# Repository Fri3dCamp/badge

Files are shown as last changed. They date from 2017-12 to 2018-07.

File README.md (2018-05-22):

# Fri3d Camp Badge 2018

De Badge voor Fri3d Camp 2018 is in volle ontwikkeling. Op dit ogenblik werken we aan het derde prototype, dat, als alles goed gaat nagenoeg de finale vorm zal hebben.

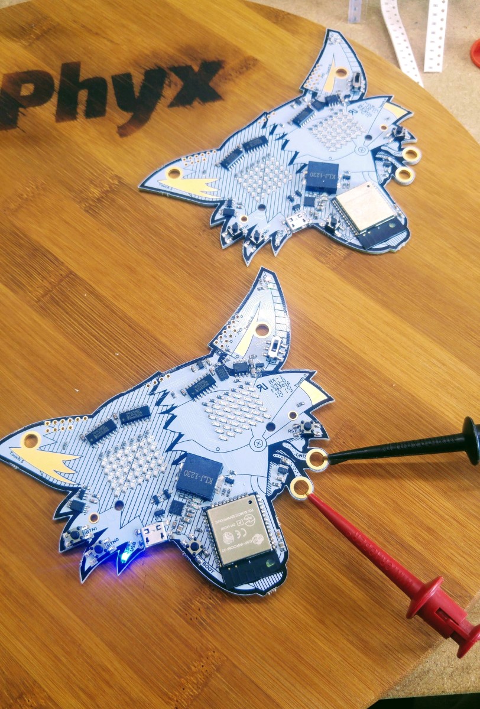
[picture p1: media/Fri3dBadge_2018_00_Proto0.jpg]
Fri3d Camp Badge prototype 3


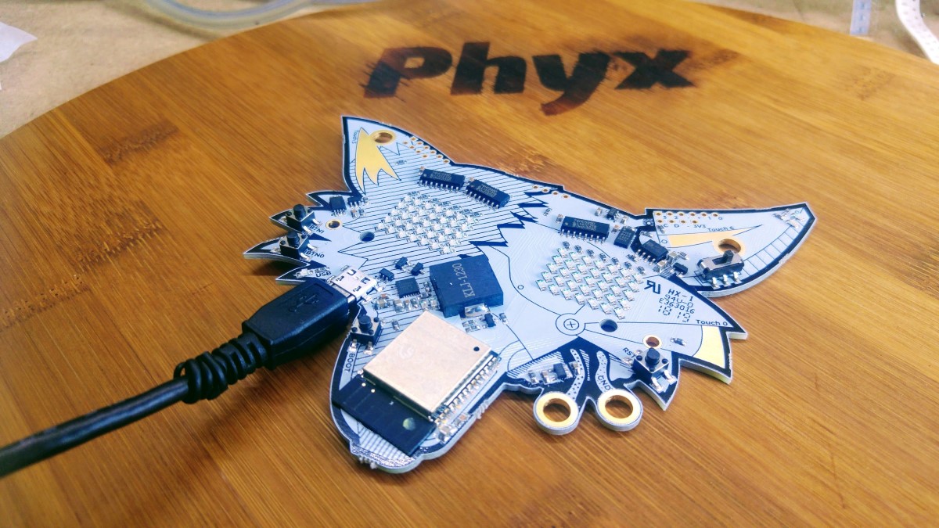
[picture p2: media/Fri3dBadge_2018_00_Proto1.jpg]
Fri3d Camp Badge prototype 3


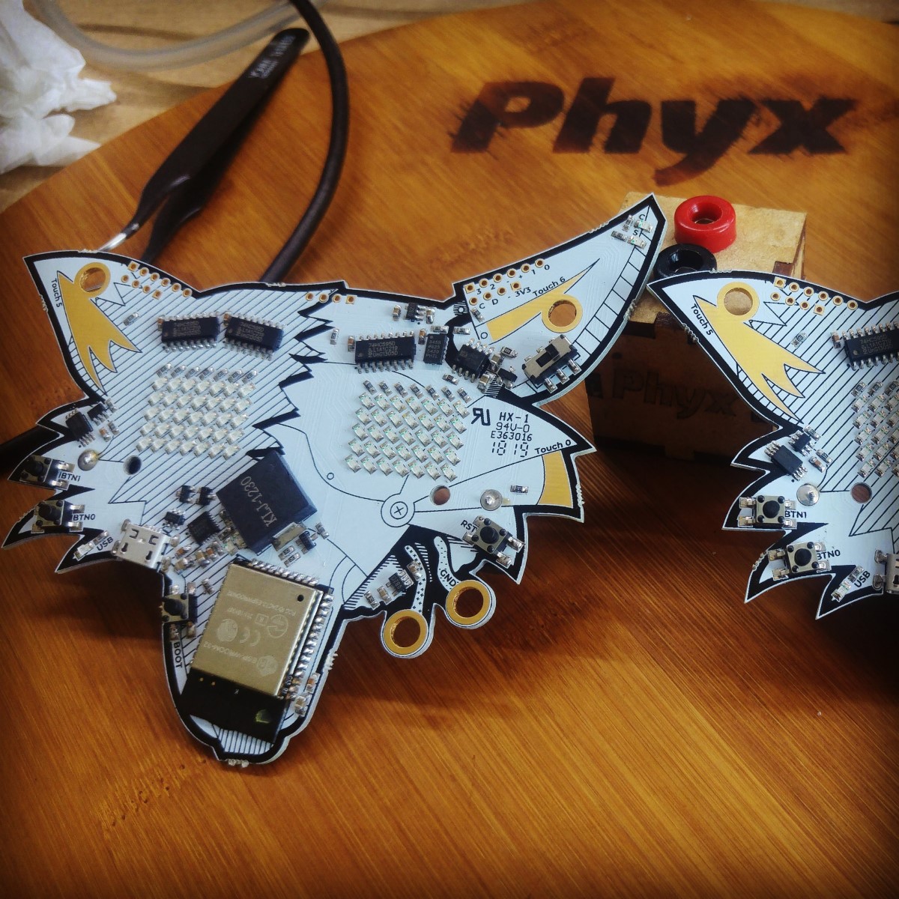
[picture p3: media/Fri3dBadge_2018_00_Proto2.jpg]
Fri3d Camp Badge prototype 3


More to come ...

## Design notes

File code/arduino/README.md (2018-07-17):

# Arduino code

The arduino code moved to its own repository: https://github.com/Fri3dCamp/Fri3dBadge

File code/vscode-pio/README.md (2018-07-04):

# Arduino library + Visual Studio Code + PlatformIO (PIO) tutorial

This tutorial shows how to program the Fri3d Camp badge using the Arduino
library in [Visual Studio Code](https://code.visualstudio.com/)
(VS Code for short), Microsoft's open source / freeware code editor in combination
with [PlatformIO](https://platformio.org/), an open source ecosystem for IoT
development.

This combination creates a powerful, fast, easy to use and cross platform IDE
for programming the Fri3d Camp badge.
PlatformIO will automatically download the necessary toolchain, compilers and
libraries and supports powerfull dependency management for Arduino libraries
(DHT, Servo, ...).
This way anyone can quickly set up a homogeneous, platform independent build
environment (Mac, Linux, Windows) and get started hacking the badge.

## Installation

* Download and install [Visual Studio Code](https://code.visualstudio.com/).
* Install the [PlatformIO IDE extension](https://platformio.org/get-started/ide?install=vscode)
in Visual Studio Code. You will be asked to reload VS Code a couple of times.
If everything went well you should be greated by the PIO Home screen in VS Code.
* You can read up on the PlatformIO documentation, browse through the supported
IoT platforms or check out some of the example projects.

## Configuration

PlatfromIO will generate a
[platformio.ini file](http://docs.platformio.org/en/latest/projectconf.html)
per project that you create.
In this file you can configure which IoT board your project uses (Arduino Uno,
ESP8266, ESP32, ...), which framework you use (Arduino, ESP-IDF, ...) and
optionally which libraries (and more importantly which version of those
libraries) your project uses (DHT temperature sensor, Servo library etc.).

This makes your project very portable between build environments.
Check out [the documentation at PlatfromIO](http://docs.platformio.org/en/latest/projectconf.html) for more information.

The Fri3d Camp badge uses the [espressif32 platform](http://docs.platformio.org/en/latest/platforms/espressif32.html).

## Example code

### Blink an LED

* Clone or download this Fri3d Camp repository if you haven't already done so.
* Open the blink example by opening the 'blink' folder under
/code/vscode-pio/examples in VS Code.
* Build the project by clicking the
checkmark in the PlatformIO toolbar at the bottom of the VS Code screen,
use the keyboard shortcut (Ctrl+Alt+b on Windows, Cmd+Shift+B on Mac) or
through the VS Code command palette (platformIO:Build).
PlatformIO should automatically download the ESP32 toolchain and its
dependencies and build the blink example without errors.
* Upload the program to your badge by clicking the right arrow icon in the
PlatformIO toolbar at the bottom, use the keyboard shortcut (Ctrl+Alt+u on
Windows, Option+Ctrl+u on Mac) or through the VS Code command palette
(platformIO:Upload).
If your badge is connected to your computer, PlatformIO should automatically
detect the port it's connected to and upload the program. The led on your
badge should start blinking.

### Use multiple cores

The ESP32 has 2 cores and is built with FreeRTOS, which allows multiple processes to run simultaneously on these cores. [This YouTube video](https://www.youtube.com/watch?v=k_D_Qu0cgu8) provides a great introduction on how to run multiple processes, use semaphores and communicate between processes with the ESP32.

The [dual core example](examples/dual_core) provides a simple example of multiple tasks running on different cores.

### Animate the eyes

TODO

### Connect to WiFi

TODO

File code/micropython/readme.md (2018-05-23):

# Fri3d Badge 2018 - MicroPython Edition

As it became a common phenomenon, every hacker camp should have their own badge. This year, we went the extra mile when designing the badge for the 2018 edition of Fri3dcamp, resulting in an awesome badge with enormous capabilities.

Apart from the very neat design (nicely done @toonvandeputte), the badge has been built around the ESP32, a very powerful microcontroller holding 2 cores as well as wifi and bluetooth (among a lot of other stuff). But there is more! We added 2 LED matrices, a piezo speaker an accelerometer and captive touch sensors to satisfy a lot of your maker needs.

If you need more, you can have a look at the Jewels; plug-on extensions providing even more functionality to the badge. Or maybe you want to design your own Jewel?     
 
We are working hard to make the badge something that stands out, so make sure to get back once in a while to check on our progress. For now, most information can be found in the docs folder.
 
## The Badge

Fri3d Camp Badge prototype 3

The badge contains the following hardware capabilities:

| component | status | description |
|---|---|---|
| Wifi | working | Connect to a wifi accesspoint or router. |
| Matrix | working | Two 5x7 LED matrices, representing eyes. |
| Accelero | working | Accelerometer measuring acceleration. |
| Buzzer | working | A piezo speaker to make some noise. |
| Touch | partially | Captive touch sensors. |
| Buttons | issues | Regular push buttons. |

## Jewels
Jewels are plug-on extensions providing extra functionality to the badge. 

### Servo Jewel
The Servo Jewel provides the badge with the ability to control up to 4 servo's. It is uses in the Robot Kit to move the legs around, but can be used in any situation where up to 4 servos have to be controlled.

## Kits
Kits are units which transforms the badge into something totally new.

### Robot Kit
The robot kit transforms the badge into a bipedal robot capable of moving around.
 
## Issues
### Buttons
Buttons do not seem to react to input. The pin values do not change during presses or releases.

### Touch Sensors
touch sensor 0 does not seem to be responding.

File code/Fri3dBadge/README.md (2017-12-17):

# Fri3d Badge Arduino Library

Deze hele folder moet je in je Arduino Libraries folder plaatsen.

Als je de hele Fri3d Badge GitHub repository hebt, kan je dit op een Unix systeem (bvb MacOS) ook doen door een link te leggen vertrekkende van de folder waar de `Fri3dBadge` folder zich bevindt.

```bash
$ ln -s `pwd`/Fri3dBadge ~/Documents/Arduino/libraries/
```

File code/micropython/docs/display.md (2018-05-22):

# Fri3dBadge Display Module

## Matrix
Er zijn twee LED matrices beschikbaar op de badge. Elke LED matrix heeft 5 rijen en 7 kolommen en je kan elke led afzonderlijk aan zetten.

### Hardware
Elk van de twee matrices is opgebouwd uit 35 blauwe LED's volgens een matrix structuur waarbij de kolommen de negatieve pool en de rijen de positieve pool voorstellen. Dit wil dus zeggen dat wanneer je aan 1 kolom een ground (GND, -) aansluit en aan 1 rij een vcc (3.3V, +) dat de led op het kruispunt van de rij en de kolom zal oplichten.
Natuurlijk is het vrij moeilijk om 35 led's aan te sturen met 1 microcontroller, aangezien we daarvoor niet voldoende pinnen vrij hebben op de microcontroller. Om dat op te lossen maken we gebruik van shift registers. Hierdoor hebben we maar 4 pinnen nodig om in totaal 70 led's aan te sturen.

Meer informatie over shift registers kan je vinden op [http://artimesdiy.nl/index.php?Itemid=76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](artimesdiy.nl)

### Software
Wanneer je binnen micropython de matrices wil gebruiken, dan kan je dit doen door middel van de ```Matrices``` klasse binnen de display module.

```python
from display import Matrices

matrices = Matrices()
```

Eenmaal je de matrices instantie beschikbaar hebt, kan je led's aan zetten door middel van de ```set(matrix, x, y)``` functie:

```python
# zet van de eerste matrix de led in de linker benedenhoek aan
matrices.set(0, 0, 0)
```

Je kan de display terug leeg maken door de ```clear()``` functie te gebruiken:

```python
matrices.clear()
```

Er draait een apparte thread op de 2e CPU die er voor zorgt dat de LED's uiteindelijk gezet worden

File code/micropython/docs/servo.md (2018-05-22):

# Servo Module

## Servo
Je kan hobby servo's aansturen met de badge. Hiervoor heb je wel een extra power board nodig omdat de servo's zelf enorm veel stroom verwachten.

### Hardware
Een hobby servo werkt op basis van een PWM (Pulse Width Modulation) signaal. Dit komt er eigenlijk op neer dat de tijd dat het signaal hoog is gebruikt wordt om gegevens door te geven. Het is dus cruciaal voor de software om binnen de juiste tijdsgrenzen te blijven. Hobby servo's verschillen ook nogal wanneer het op deze tijdsgrenzen aankomt, dus het kan zijn dat je je code straks gaat moeten aanpassen op jouw specifieke servo's.

### Software

TBD

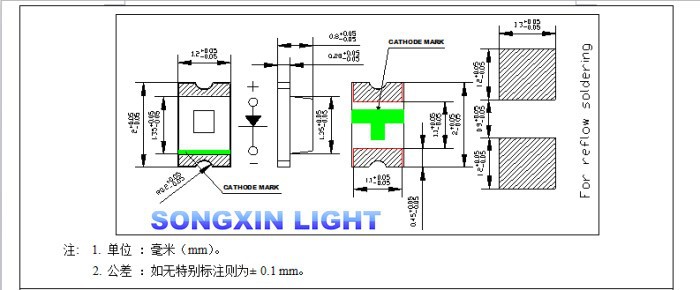
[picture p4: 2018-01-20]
datasheets/yellow-led.jpg

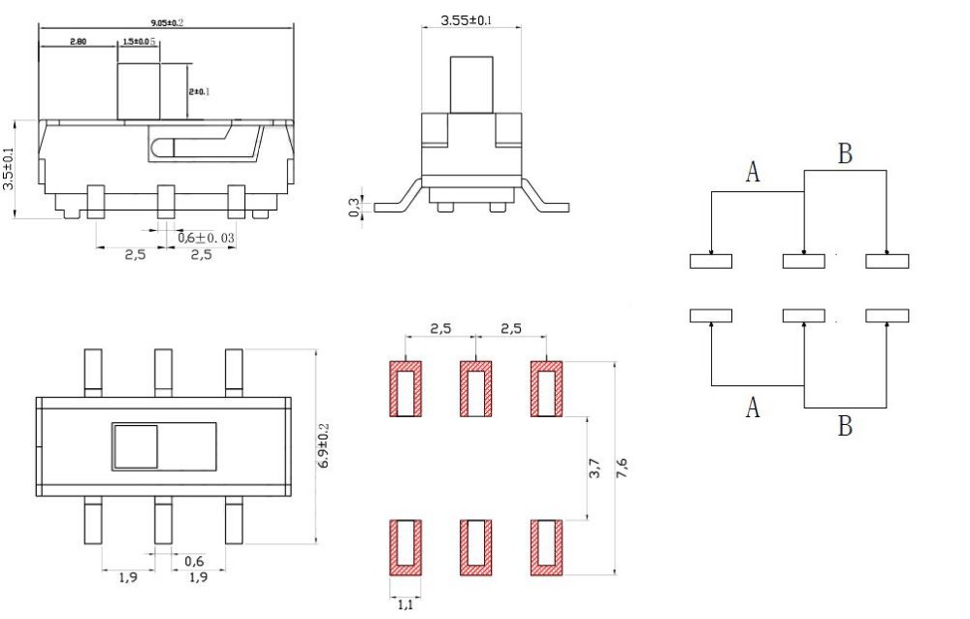
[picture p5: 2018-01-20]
datasheets/slide-switch.jpg

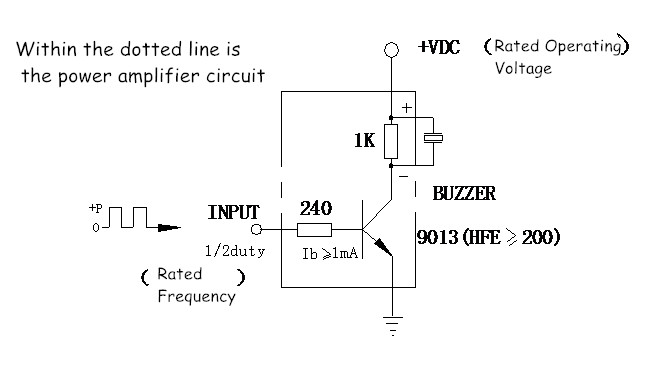
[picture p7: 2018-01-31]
datasheets/klj-1230.jpg

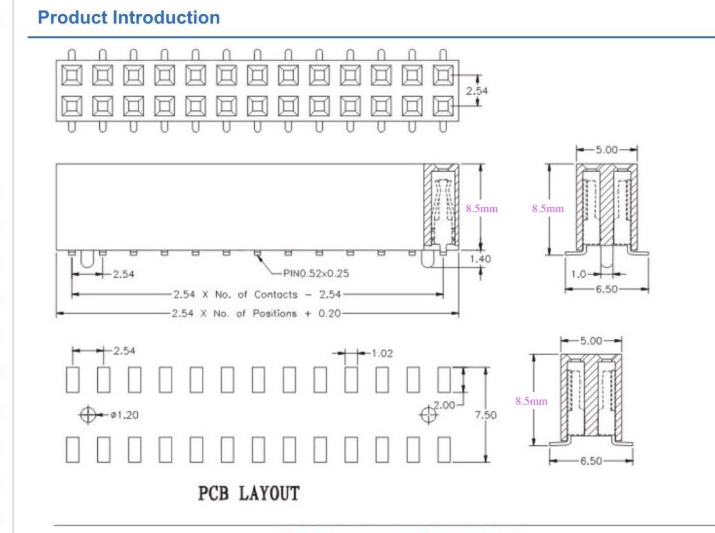
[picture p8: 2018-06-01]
datasheets/2x6_header_SMD.jpg

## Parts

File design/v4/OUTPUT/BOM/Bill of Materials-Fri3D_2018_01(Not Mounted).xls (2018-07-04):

Bill of Materials |  |  | Fri3D Badge 2018
Project: |  | Fri3D_2018_01.PrjPcb
Revision: |  | 01
Variant: |  | Not Mounted
Creation Date: | 13/06/2018 | 17:10:01
Print Date: | 2018-06-13 | 17:38:40
Footprint | Comment | LibRef | Designator | Value | Description | Supplier 1 | Supplier PN 1 | Qty
MPD_BH-18650-PC | 18650 Battery holder | 18650 Battery holder BH-18650-PC | BAT1 | BH-18650-PC |  | Digikey |  | 1
CUI_CMT-1203-SMT | 12x12x3mm Piezo Buzzer Transducer 81dB | BUZ # CUI CMT-1203-SMT | BUZ1 | CMT-1203-SMT | Crystal Oscillator | Digikey | 102-2197-1-ND | 1
C0603_N |  | CAP # 100nF 16V 0603 | C1, C3, C5, C6, C7, C12, C17, C19 | 100nF 16V | Capacitor Ceramic |  |  | 8
C0805_N | CAP_CERAMIC | CAP # 10uF 10V 0805 | C4, C15, C16, C18, C20 | 10uF 10V | Capacitor Ceramic | Farnell | 2320859 | 5
C0603_N | CAP_CERAMIC | CAP # 1uF 16V 0603 | C8, C9, C10, C11 | 1uF 16V | Capacitor Ceramic | Farnell | 2320814 | 4
NXP_SOT457 | TVS Diode Dual USB | TVS # IP4220CZ6 Dual USB | D1 | IP4220CZ6 |  | Farnell | 2143248 | 1
LED_0805_BL | Default 0805 Blue LED | LED # Blue 0805 | D2, D3, D4, D5, D6, D7, D8, D9, D10, D11, D12, D13, D14, D15, D16, D17, D18, D19, D20, D21, D22, D23, D24, D25, D26, D27, D28, D29, D30, D31, D32, D33, D34, D35, D36, D37, D38, D39, D40, D41, D42, D43, D44, D45, D46, D47, D48, D49, D50, D51, D52, D53, D54, D55, D56, D57, D58, D59, D60, D61, D62, D63, D64, D65, D66, D67, D68, D69, D70, D71, D76 |  |  | Farnell | 2217980 | 71
LED_0805_GR | Default 0805 Green LED | LED # Green 0805 | D72, D75 |  |  | Farnell | 2099239 | 2
LED_0805_RD | Default 0805 Red LED | LED # Red 0805 | D73, D74 |  |  | Farnell | 2099236 | 2
FCI_10118194-0001LF | Amphenol FCI 10118194-0001LF Micro USB 1.8A TH Lock | USB # Micro B TH Amphenol 10118194-0001LF | J2 | 10118194-0001LF |  | Farnell | 2668482 | 1
ESP-WROOM-32 | ESP-32 based ESP-WROOM-32 | WiFi # MOD ESP-WROOM-32 | MOD1 | ESP-WROOM-32 | WiFi # MOD ESP-WROOM-32 | Espressif | ESP-WROOM-32 | 1
WE_610312243021_POST | Receptacle 6x2 SMD low profile | Receptacle # 2.54mm dual row 12way 610312243021 | P1, P2 | 610312243021 |  | Wurth | 610312243021 | 2
R0603_N | RESISTOR | RES # 1K2 0603 | R1, R2, R18, R21, R22, R23, R24, R25, R26, R27 | 1K2 |  |  |  | 10
R0603_N | RESISTOR | RES # 100R 0603 | R3, R4, R5, R6, R7, R8, R9, R10, R11, R12, R13, R14, R15, R16, R17, R20, R30, R37, R38 | 100R |  |  |  | 19
R0603_N | RESISTOR | RES # 10K 0603 | R28, R29, R31, R34, R35, R36, R39, R40 | 10K |  | Farnell | 2502397 | 8
WE_430181038816 | 4.5x4.5mm tact SMD H3,8mm | SW # TACT small 4.5x4.5mm SMD WS-TASV | SW1, SW2, SW3, SW4 | 430181038816 |  | Wurth | 430181038816 | 4
MSS22D18 | Mini slide switch 2P2T | SW # 2P2T mini slide MSS22D18 | SW5 | MSS22D18 |  | AliExpress | MSS22D18 | 1
TSSOP_8_65P | Dual N-Ch MOSFET Common Drain | FS8205A Dual N-Ch common Drain for DW01-P | T1 | FS8205A |  | AliExpress | FS8205A | 1
SOT23-3 | 0.2A N-Ch MOSFET Vgs 3.2 | BSS138 N-Ch MOSFET 0.2A 3.2Vgs 60Vds | T2, T3, T4 | BSS138 |  | Farnell | 2432717 | 3
AD_CC-14-1 | 3-Axis, ±2 g/±4 g/±8 g/±16 g Digital Accelerometer | ACCELERO # ADXL345 | U1 | ADXL345BCCZ |  | Farnell | 1853935 | 1
SOIC_N_16 | 8-Bit Shift Registers With 3-State Output Registers | IOEXP # SHIFT 74HC595 8-bit | U2, U3, U4 | 74HC595 |  | Farnell | 1278491 | 3
SOT23-5 | 3V3 LDO 700mA 50mV | LDO # 3V3 XC6210B33 | U5, U6 | XC6210B332MR |  | Farnell | 1057803 | 2
SOT23-6 | DW01-P single cell lithium protection | PWR # DW01-P Lithium protection | U7 | DW01-P |  | Aliexpress | DW01-P | 1
SOIC_N_8_TH | Single Cell LiIon charger max 1A | CHG # TP4056 LiIon 1A | U8 | TP4056 |  | Aliexpress | TP4056 | 1
QFN_24 | USB to UART 3.3-5V | CP2102N # QFN24 USB UART | U9 | CP2102N-A01-GQFN24 |  | Farnell | 2577278 | 1
 |  |  |  |  |  |  |  | 154
Approved |  | Notes

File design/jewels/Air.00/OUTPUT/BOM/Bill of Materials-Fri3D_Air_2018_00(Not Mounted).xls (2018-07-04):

Bill of Materials |  |  | Fri3D Air 2018
Project: |  | Fri3D_Air_2018_00.PrjPcb
Revision: |  | 00
Variant: |  | Not Mounted
Creation Date: | 21/05/2018 | 22:15:40
Print Date: | 2018-05-23 | 15:10:44
Footprint | Comment | LibRef | Designator | Value | Description | Supplier 1 | Supplier Part Number 1 | Quantity | Quantity
C0805_N | CAP_CERAMIC | CAP # 10uF 10V 0805 | C2, C6 | 10uF 10V | Capacitor Ceramic | Farnell | 2320859 | 2
C0603_N |  | CAP # 100nF 16V 0603 | C4 | 100nF 16V | Capacitor Ceramic |  |  | 1
ON_SOD-123FL | NTS260SFT1G Schottky Rectifier, Single, 60 V, 2 A, SOD-123, 650 mV | Schottky # NTS260SFT1G | D1 | NTS260SFT1G |  | Farnell | 2473419 | 1 | Farnell | 2473419
SNL_SWPA4020 | SWPA4020S4R7MT | IND # 4u7H SWPA4020 | L1 | 4u7H |  | China | SWPA4020S4R7MT | 1 | Farnell | 2771305
WE_68800511722 | Header 2.5mm RA Shrouded 5 | HDR # RA SHR 2.5mm 5way - 68800511722 | P1 | 68800511722 |  | Wurth | 68800511722 | 1
HDR1X6 | Header 6 | Pin Header 2.54mm 6way | P2 |  |  |  |  | 1
HDR1X5 | Header 5 | Pin Header 2.54mm 5way | P3 |  |  |  |  | 1
HDR1X4 | Header 4 | Pin Header 2.54mm 4way | P5, P6 |  |  |  |  | 2
R0603_N | RESISTOR | RES # 82K 0603 | R1 | 82K |  |  |  | 1
R0603_N | RESISTOR | RES # 10K 0603 | R2 | 10K |  | Farnell | 2502397 | 1
R0603_N | RESISTOR | RES # 1K 0603 | R3 | 1K |  |  |  | 1
SOT23-6 | High Efficiency 1.2MHz 2A Step Up Converter SX1308 | PWR # Boost SX1308 | U1 | SX1308 |  |  |  | 1
 |  |  |  |  |  |  |  | 14
Approved |  | Notes

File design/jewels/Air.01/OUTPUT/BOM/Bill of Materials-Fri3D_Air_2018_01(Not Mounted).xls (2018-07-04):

Bill of Materials |  |  | Fri3D Air 2018
Project: |  | Fri3D_Air_2018_01.PrjPcb
Revision: |  | 01
Variant: |  | Not Mounted
Creation Date: | 12/06/2018 | 21:47:38
Print Date: | 2018-06-14 | 8:22:58
Footprint | Comment | LibRef | Designator | Value | Description | Supplier 1 | Supplier Part Number 1 | Qty
C0805_N | CAP_CERAMIC | CAP # 10uF 10V 0805 | C2, C6 | 10uF 10V | Capacitor Ceramic | Farnell | 2320859 | 2
C0603_N |  | CAP # 100nF 16V 0603 | C4 | 100nF 16V | Capacitor Ceramic |  |  | 1
TS_SOD128 | TSS83L45 MWG Schottky ULTRAFAST, 3A, 45V | Schottky # TSS83L45MWG 3A 45V | D1 | TSS83L45 MWG |  | Digi-key | TSS83L45MWGCT-ND | 1
SNL_SWPA4020 | SWPA4020S4R7MT | IND # 4u7H SWPA4020 | L1 | 4u7H |  | China | SWPA4020S4R7MT | 1
WE_68800511722 | Header 2.5mm RA Shrouded 5 | HDR # RA SHR 2.5mm 5way - 68800511722 | P1 | 68800511722 |  | Wurth | 68800511722 | 1
HDR1X6 | Header 6 | Pin Header 2.54mm 6way | P2 |  |  |  |  | 1
HDR1X5 | Header 5 | Pin Header 2.54mm 5way | P3 |  |  |  |  | 1
HDR1X4 | Header 4 | Pin Header 2.54mm 4way | P5, P6 |  |  |  |  | 2
R0603_N | RESISTOR | RES # 82K 0603 | R1 | 82K |  |  |  | 1
R0603_N | RESISTOR | RES # 10K 0603 | R2 | 10K |  | Farnell | 2502397 | 1
R0603_N | RESISTOR | RES # 1K 0603 | R3 | 1K |  |  |  | 1
SOT23-6 | High Efficiency 1.2MHz 2A Step Up Converter SX1308 | PWR # Boost SX1308 | U1 | SX1308 |  |  |  | 1
 |  |  |  |  |  |  |  | 14
Approved |  | Notes

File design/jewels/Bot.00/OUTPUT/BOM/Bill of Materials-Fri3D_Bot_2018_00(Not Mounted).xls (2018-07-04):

Bill of Materials |  |  | Fri3D Bot 2018
Project: |  | Fri3D_Bot_2018_00.PrjPcb
Revision: |  | 00
Variant: |  | Not Mounted
Creation Date: | 12/06/2018 | 22:04:56
Print Date: | 2018-06-14 | 8:24:33
Footprint | Comment | LibRef | Designator | Value | Description | Supplier 1 | Supplier Part Number 1 | Qty
MPD_BH-18650-PC | 18650 Battery holder | 18650 Battery holder BH-18650-PC | BAT1 | BH-18650-PC |  | Digikey |  | 1
C1210_N | CAP_CERAMIC | CAP # 22uF 10V 1210 X5R | C3, C7, C9, C13 | 22uF 10V | Capacitor Ceramic |  |  | 4
C0805_N | CAP_CERAMIC | CAP # 10uF 10V 0805 | C4, C5, C6, C8, C10, C11 | 10uF 10V | Capacitor Ceramic | Farnell | 2320859 | 6
C0603_N |  | CAP # 100nF 16V 0603 | C12 | 100nF 16V | Capacitor Ceramic |  |  | 1
TS_SOD128 | TSS83L45 MWG Schottky ULTRAFAST, 3A, 45V | Schottky # TSS83L45MWG 3A 45V | D1, D2 | TSS83L45 MWG |  | Digi-key | TSS83L45MWGCT-ND | 2
LED_0805_RD | Default 0805 Red LED | LED # Red 0805 | D3, D5 | Red |  | Farnell | 2099236 | 2
LED_0805_GR | Default 0805 Green LED | LED # Green 0805 | D4 | Green |  | Farnell | 2099239 | 1
FCI_10118194-0001LF | Amphenol FCI 10118194-0001LF Micro USB 1.8A TH Lock | USB # Micro B TH Amphenol 10118194-0001LF | J1 | 10118194-0001LF |  | Farnell | 2668482 | 1
SNL_SWPA4020 | SWPA4020S4R7MT | IND # 4u7H SWPA4020 | L5, L6 | 4u7H |  | China | SWPA4020S4R7MT | 2
HDR1X6 | Header 6 | Pin Header 2.54mm 6way | P1 |  |  |  |  | 1
HDR1X4 | Header 4 | Pin Header 2.54mm 4way | P3 |  |  |  |  | 1
HDR1X3 | Header 3 | Pin Header 2.54mm 3way | P4, P6, P7, P8 |  |  |  |  | 4
R0603_N | RESISTOR | RES # 82K 0603 | R1, R4 | 82K |  |  |  | 2
R0603_N | RESISTOR | RES # 10K 0603 | R2, R5 | 10K |  | Farnell | 2502397 | 2
R0603_N | RESISTOR | RES # 1K2 0603 | R3, R6, R7, R8, R9, R10, R11, R18 | 1K2 |  |  |  | 8
R0603_N | RESISTOR | RES # 100R 0603 | R17 | 100R |  |  |  | 1
SK-12D07 | mini Switch 1 pole double throw right angle | SW 1P2T micro RA SK-12D07 | SW1 | SK-12D07 |  | AliExpress | SK-12D07 | 1
TSSOP_8_65P | Dual N-Ch MOSFET Common Drain | FS8205A Dual N-Ch common Drain for DW01-P | T1 | FS8205A |  | AliExpress | FS8205A | 1
SOT23-6 | High Efficiency 1.2MHz 2A Step Up Converter SX1308 | PWR # Boost SX1308 | U1, U2 | SX1308 |  |  |  | 2
SOIC_N_8_TH | Single Cell LiIon charger max 1A | CHG # TP4056 LiIon 1A | U3 | TP4056 |  | Aliexpress | TP4056 | 1
SOT23-6 | DW01-P single cell lithium protection | PWR # DW01-P Lithium protection | U7 | DW01-P |  | Aliexpress | DW01-P | 1
 |  |  |  |  |  |  |  | 45
Approved |  | Notes

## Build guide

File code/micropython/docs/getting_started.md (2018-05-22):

# Getting Started

## Connect the badge to your laptop or pc
You can connect the badge to your laptop or pc using a micro-usb cable. In some cases you may need to install a driver as well for the badge to be recognized. That driver can be found at ```https://www.silabs.com/products/development-tools/software/usb-to-uart-bridge-vcp-drivers```

## Micropython on the badge

Get the micropython image for the ESP32 from ```https://micropython.org/download/#esp32```

In order to flash the image file to the badge, you will need a python tool called ```esptool.py```. Luckily you can install this tool using pip:

```
pip install esptool
```

Once we have installed esptool and downloaded the image, we can start the flashing process. The first time we will need to clean the flash memory of the badge by using the esptool.py script:

```
esptool.py --chip esp32 --port /dev/cu.SLAB_USBtoUART erase_flash
```

```
esptool.py --chip esp32 --port /dev/cu.SLAB_USBtoUART write_flash -z 0x1000 <path to the .bin file>
```

Once the process has finished you will have micropython available on the badge.

## Invoking python commands
A repl (python commandline) is available when connecting to the badge over usb. on mac and linux, the screen command allows you to access the repl by invoking:

```
screen /dev/cu.SLAB_USBtoUART 115200
```

## Deploying programs

To make interacting with the badge a bit easier, we are going to install a tool called ```ampy```. It was developed by adafruit to make interacting with circuitpython (a micropython adoption by adafruit) easier to work with.

Installing ampy is pretty straightforward as it is available using pip:
```
pip install adafruit-ampy
```

Once ampy is installed, you may run the following command to get an overview of the files that are available on the badge:

```
ampy -p /dev/cu.SLAB_USBtoUART ls
```

you will notice a file called ```boot.py```. This is the default file that is being ran when the badge is powered on. You can overwrite this file with your own version to execute your program.

## Blinking LED example

Create a file on your computer, `blink.py` with the following contents:

```
import time
from machine import Pin
led = Pin(2, Pin.OUT)
while True:
    led(1)
    time.sleep(1)
    led(0)
    time.sleep(1)
```

This little python program sets pin 2 (connected to an LED) as an output pin and indefinitely blinks the LED.

You can run this program on the ESP32 by executing the following `ampy` command:

`ampy --port /dev/tty.SLAB_USBtoUART run blink.py`

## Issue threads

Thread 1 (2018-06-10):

Is er interesse in een json bestand zodat alles direct in arduino ide en sloeber kan geladen worden?

jantje, 2018-06-10:
Ik wil zo wel een maken maar  als er geen interesse is .....

Brubacker, 2018-06-12:
Zeer zeker interessant, echter is het op de ESP32 gebaseerd dus moet je wel de juiste [compilers etc installeren](https://github.com/espressif/arduino-esp32).

michaelshmitty, 2018-06-12:
Ik denk dat je ook PlatformIO zou kunnen gebruiken (https://platformio.org/). Je hebt dan een platformio.ini file waarin alle build informatie staat (target platform, juiste versie van libs etc).
Ik heb het zelf nog niet gebruikt maar ik weet dat het luftdaten.info project platformio gebruikt voor hun stofsensor firmware te bouwen.

Alleszins vlotter dan manueel de arduino IDE te moeten installeren, de esp32 toolchain, de juist versies van de juiste libs etc.

Als ik tijd vind dan wil ik het wel eens bekijken. Altijd al eens willen uitproberen.

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

jantje, 2018-06-12:
>Alleszins vlotter dan manueel de arduino IDE te moeten installeren, de esp32 toolchain, de juist versies van de juiste libs etc.

Platformio installatie is niet zoveel makkelijker dan Arduino ide en Sloeber.
Platformio is ook niet open source
Ik denk/hoop dat het enigste wat mist ieen esp32 json file is. Als dat zo is zorg ik er wel voor

michaelshmitty, 2018-06-12:
> Platformio installatie is niet zoveel makkelijker dan Arduino ide en Sloeber.
Geen idee, was er net mee begonnen. Ik kijk ook eens naar Sloeber want dat ken ik nog niet.

> Platformio is ook niet open source
"PlatformIO is an open source ecosystem for IoT development" staat nochtans in grote letters op de homepagina https://platformio.org
Ja er is ook een "Plus" versie die misschien niet open source is, maar veel projecten gebruiken zo'n model.

Brubacker, 2018-06-12:
> Ik denk/hoop dat het enigste wat mist ieen esp32 json file is. Als dat zo is zorg ik er wel voor

Helaas is het niet enkel de json file, maar moet je ook de compiler nog installeren
Voor Debian / Ubuntu: https://github.com/espressif/arduino-esp32/blob/master/docs/arduino-ide/debian_ubuntu.md
Voor Windows : https://github.com/espressif/arduino-esp32/blob/master/docs/arduino-ide/windows.md
Voor Mac : https://github.com/espressif/arduino-esp32/blob/master/docs/arduino-ide/mac.md

> Platformio installatie is niet zoveel makkelijker dan Arduino ide en Sloeber.

Voor Platformio zijn ook instructies beschikbaar. https://github.com/espressif/arduino-esp32/blob/master/docs/platformio.md

michaelshmitty, 2018-06-12:
Ok net PlatformIO geïnstalleerd in VS Code. Heb ook even naar Sloeber gekeken. Ik heb de indruk dat Eclipse + Sloeber == VS Code (of Atom, maar VS Code is stukken sneller en beter imho). Ik gebruik zelf geen Eclipse maar als ik het goed voor heb kan iets zoals Sloeber er net als platformio voor vscode voor zorgen dat lib dependencies enzo bijgehouden worden. Dat is wel een voordeel t.o.v. de Arduino IDE. Tenzij die ook zoiets ondersteund om lib deps (met de juiste versie) bij te houden.
Op een project als dit met een ESP en nog wat randapparatuur is het misschien wel een goed idee om zo'n dependency lijst mee in de repo bij te houden. Dat maakt het clonen, builden en uploaden mogelijk toch wat vlotter en kunnen mensen sneller aan de slag.

Een build systeem opzetten is niet meteen het tofste werk voor hackers/makers die snel met de badge aan de slag willen.

calmera, 2018-06-13:
ik ben redelijk wat bezig geweest om de ESP32 aan het werken te krijgen met VSCode, om te beginnen schrijven aan de Fri3d arduino library. To be honest, it is a serious PITA. Als er iemand is die het op zich wil nemen om dit op te zetten/beschrijven/... dan wil ik gerust wel kijken om de micropython lib te porten naar arduino.

michaelshmitty, 2018-06-13:
Ik heb gisteren VSCode + de PlatformIO plugin gebruikt voor twee ESP8266 gebaseerde bordjes (de Wemos D1 Mini en een Nodemcu) en dat ging erg vlot. Dat was op een vanilla Windows PC waar nog niets van toolchains op stond. PlatformIO download automatisch de nodige toolchain, libraries en tools, inclusief de Arduino library voor de ESP8266.
Ik weet niet of het voor de ESP32 even vlot gaat want ik heb zo geen bordje. Volgens de [PlatformIO website](https://platformio.org/platforms/espressif32) zou die wel goed ondersteund zijn.

@calmera Ik wil dat graag opzetten en beschrijven. Misschien kan @jantje dan een gids voor Sloeber doen. Dan hebben we een breed gamma aan IDE's / tools om met de badge aan de slag te kunnen.
Om te testen zou ik wel een ESP32 zoals op de badge gebruikt wordt in handen moeten krijgen. Dat moet niet perse de Fri3d Camp badge zijn. Een eenvoudige breakout met usb connectie is ook al goed. Ik ben morgenavond in de Open Garage, misschien kan ik er zo wel aan geraken?

calmera, 2018-06-13:
@michaelshmitty Sure, anthony heeft nog een wemos ESP32 liggen van mij, vraag hem die even en dan ben je normaal vertrokken.

https://community.platformio.org/t/the-esp32-platformio-is-a-game-changer/3194

lijkt me interessant, maar is ESP-IDF. Mijn ervaring (als je daar al over kan spreken) was voornamelijk met platformio + arduino

michaelshmitty, 2018-06-13:
@calmera PlatformIO ondersteunt het Arduino framework voor de ESP32: http://docs.platformio.org/en/latest/platforms/espressif32.html#frameworks

jantje, 2018-06-23:
Deze werkt bij mij in windows 10
https://raw.githubusercontent.com/jantje/arduino-esp32/master/package/package_Espressif_esp32_index.json
Het zou ook moeten werken op andere oses

jantje, 2018-06-26:
Heeft er al iemand geprobeerd?

Brubacker, 2018-06-26:
Net een test gedaan op Ubuntu 18.04 LTS x64 met Arduino 1.8.5 x64 en kreeg de melding dat de esptool niet beschikbaar was voor mijn OS.

jantje, 2018-06-26:
Inderdaad die zit er niet tussen. En met de get krijg je die wel?
Weet jij waar je die kan downloaden?
En de 32 bit versie?

jantje, 2018-06-26:
Ik vraag dat want zover ik de code begrijp is deze file https://github.com/espressif/arduino-esp32/blob/master/package/package_esp32_index.template.json#L87
de enigste die referenties bevat. En er zit er geen in voor linux. Misschien is de macos ook gebruikt voor linux?

Brubacker, 2018-06-27:
Ziet er naar uit dat die nog niet werkt :
https://github.com/espressif/arduino-esp32/issues/515

jantje, 2018-06-27:
Dit is een json die ik gemaakt heb. Nadat ik gezocht had op een bestaande json en niks vond.
Ik heb ook de platform.txt aangepast  om het te doen werken.
Het werkt ook op windows (bij mij en iemand anders)
Alleen weet ik niet welke esptool er in linux wordt geinstalleerd.
Als je get draaid in linux zie je de naam van de gedownloade bestanden en die zou ik moeten hebben.

jantje, 2018-07-02:
espresif is in actie geschoten  https://dl.espressif.com/dl/package_esp32_dev_index.json

Brubacker, 2018-07-03:
Lijkt te werken op Win10 x64 met Arduino 1.8.5

jantje, 2018-07-03:
En er zijn links voor esptool in linux :-)
Ik denk dat deze issue dan ook kan ggesloten worden tenzij er vraag is voor een fried board met alle opties die geen opties zijn voorgekozen.

Brubacker, 2018-07-18:
Arduino ontwikkeling in andere repo -> https://github.com/Fri3dCamp/Fri3dBadge

Closed 2018-07-18.

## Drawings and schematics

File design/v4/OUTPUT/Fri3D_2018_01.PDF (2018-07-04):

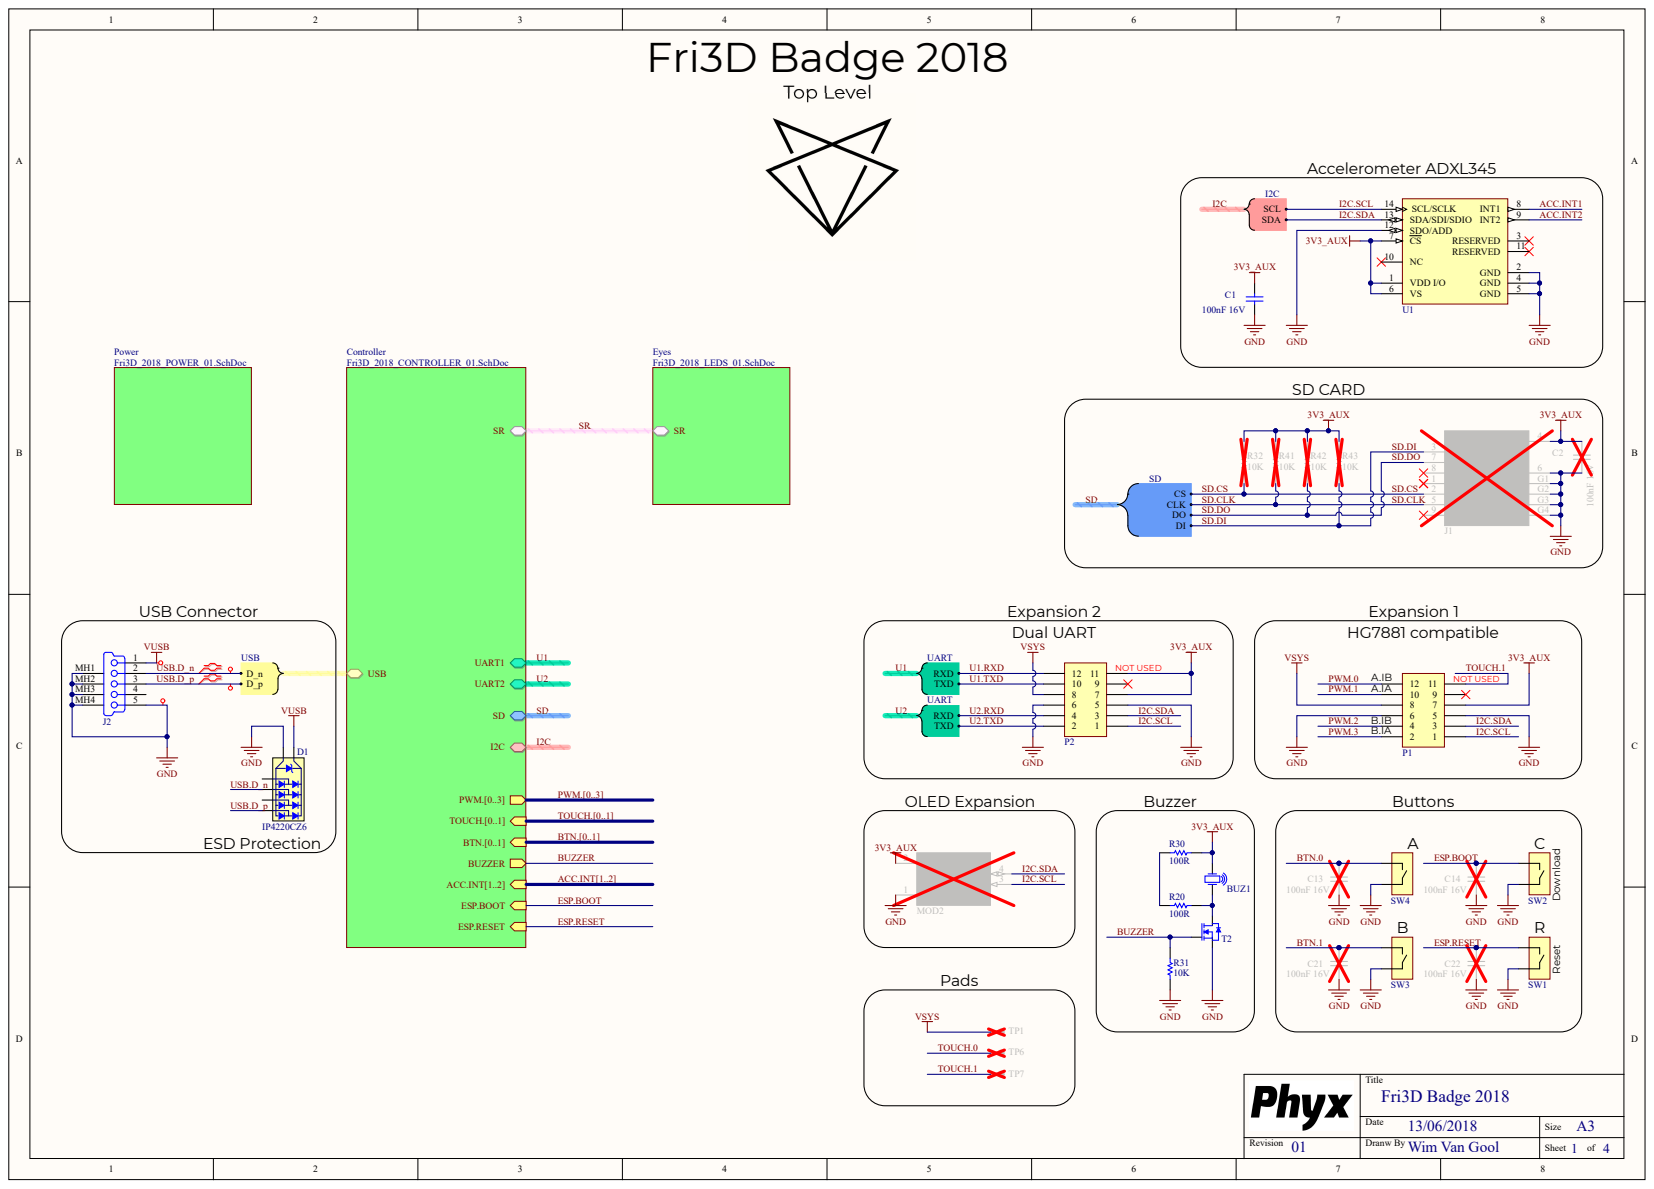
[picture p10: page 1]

SD.DO
SD.CS | DAT1 8

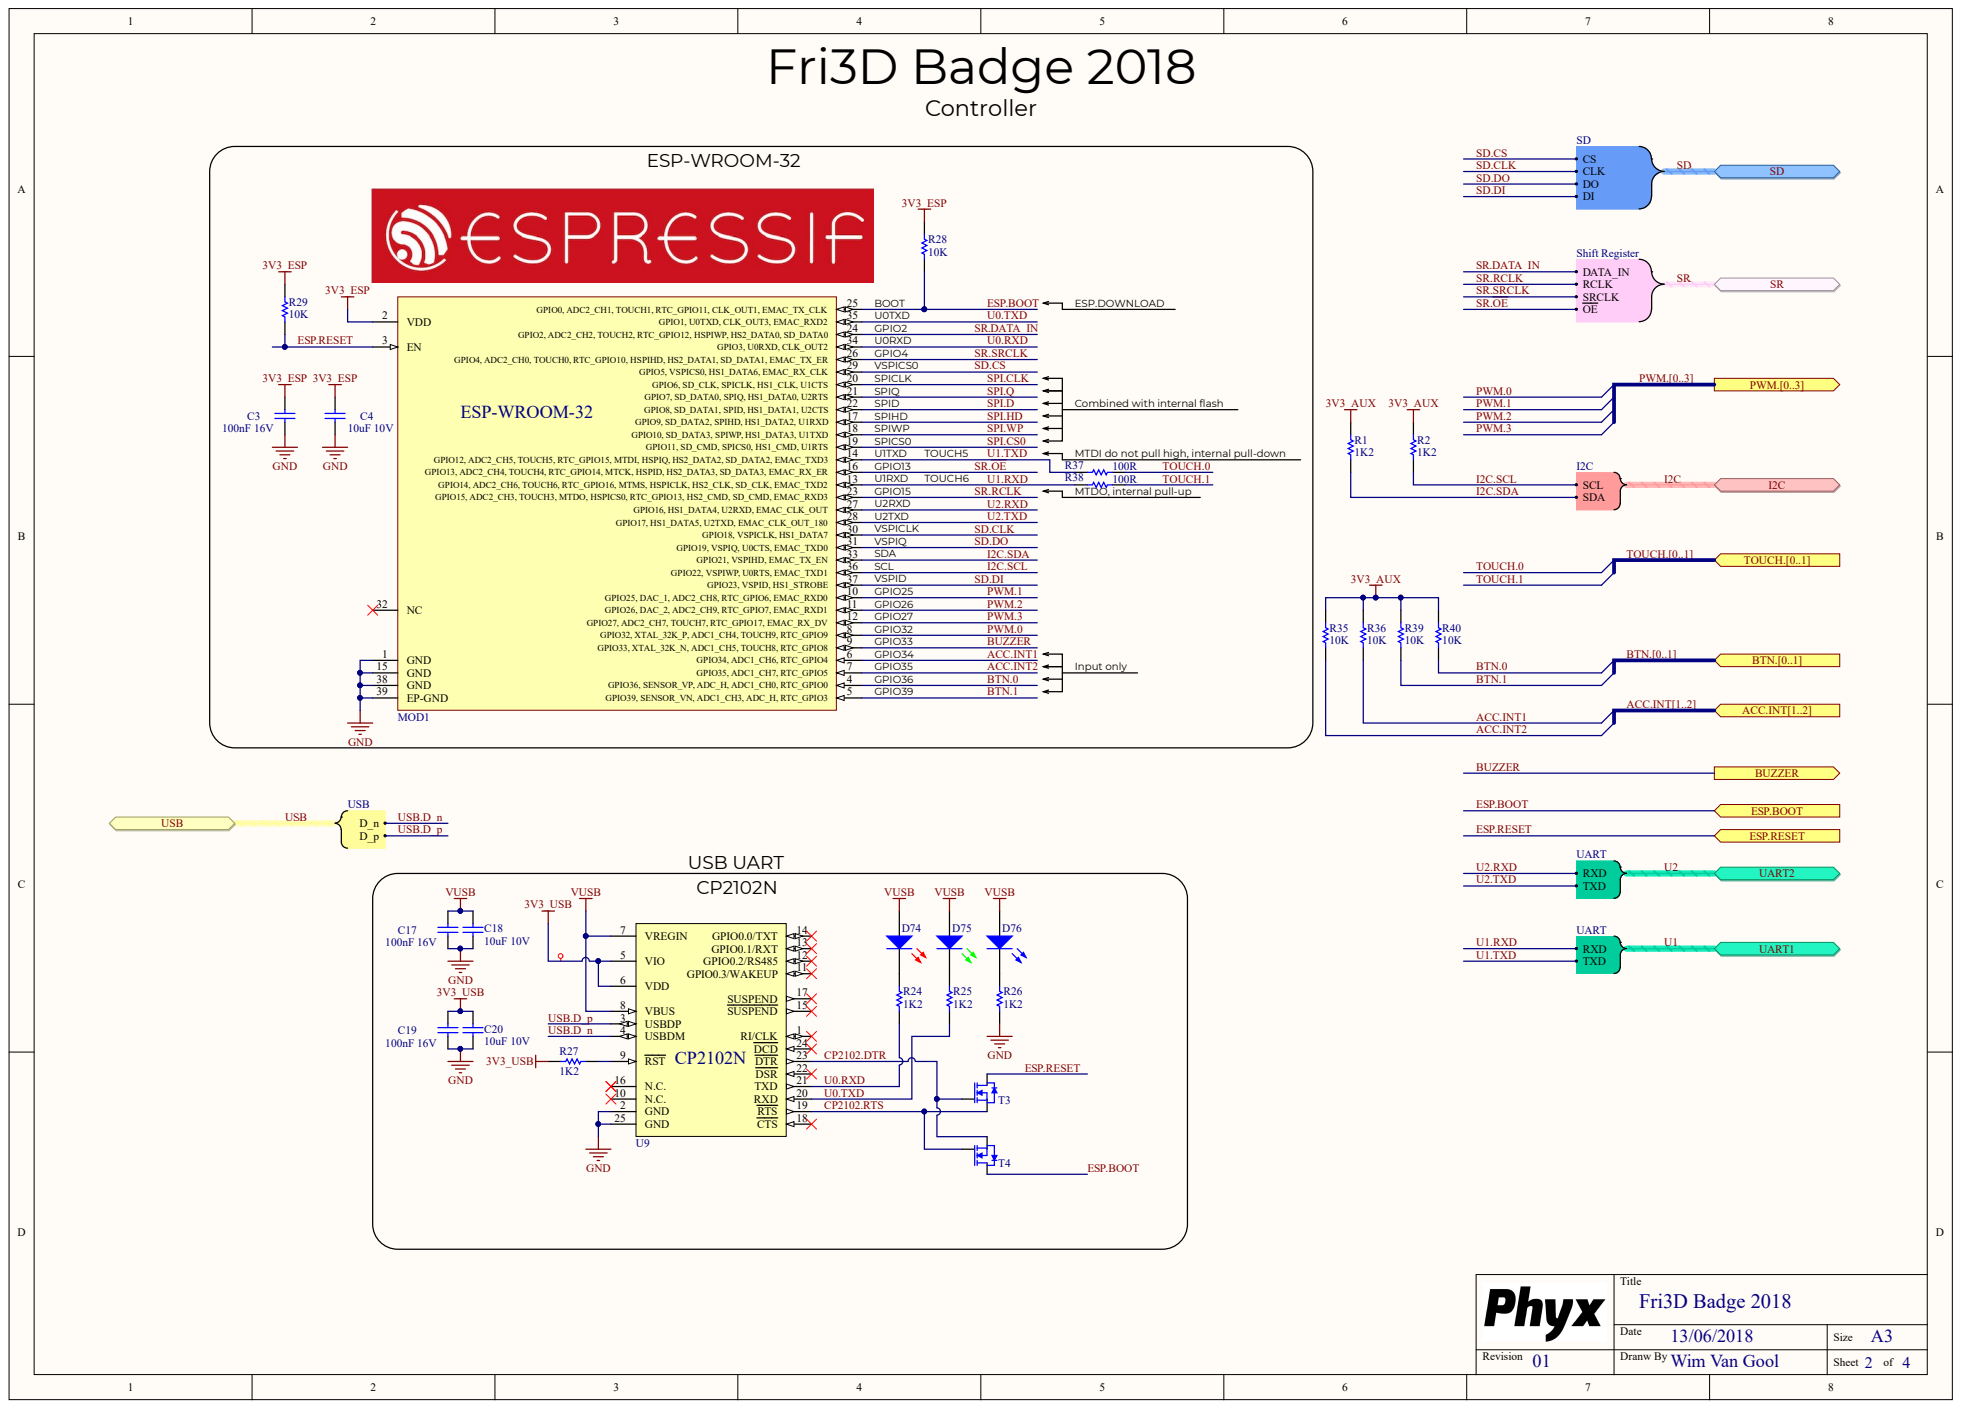
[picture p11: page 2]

ACC.INT[1..2]

N.C. 10 | U0.TXD

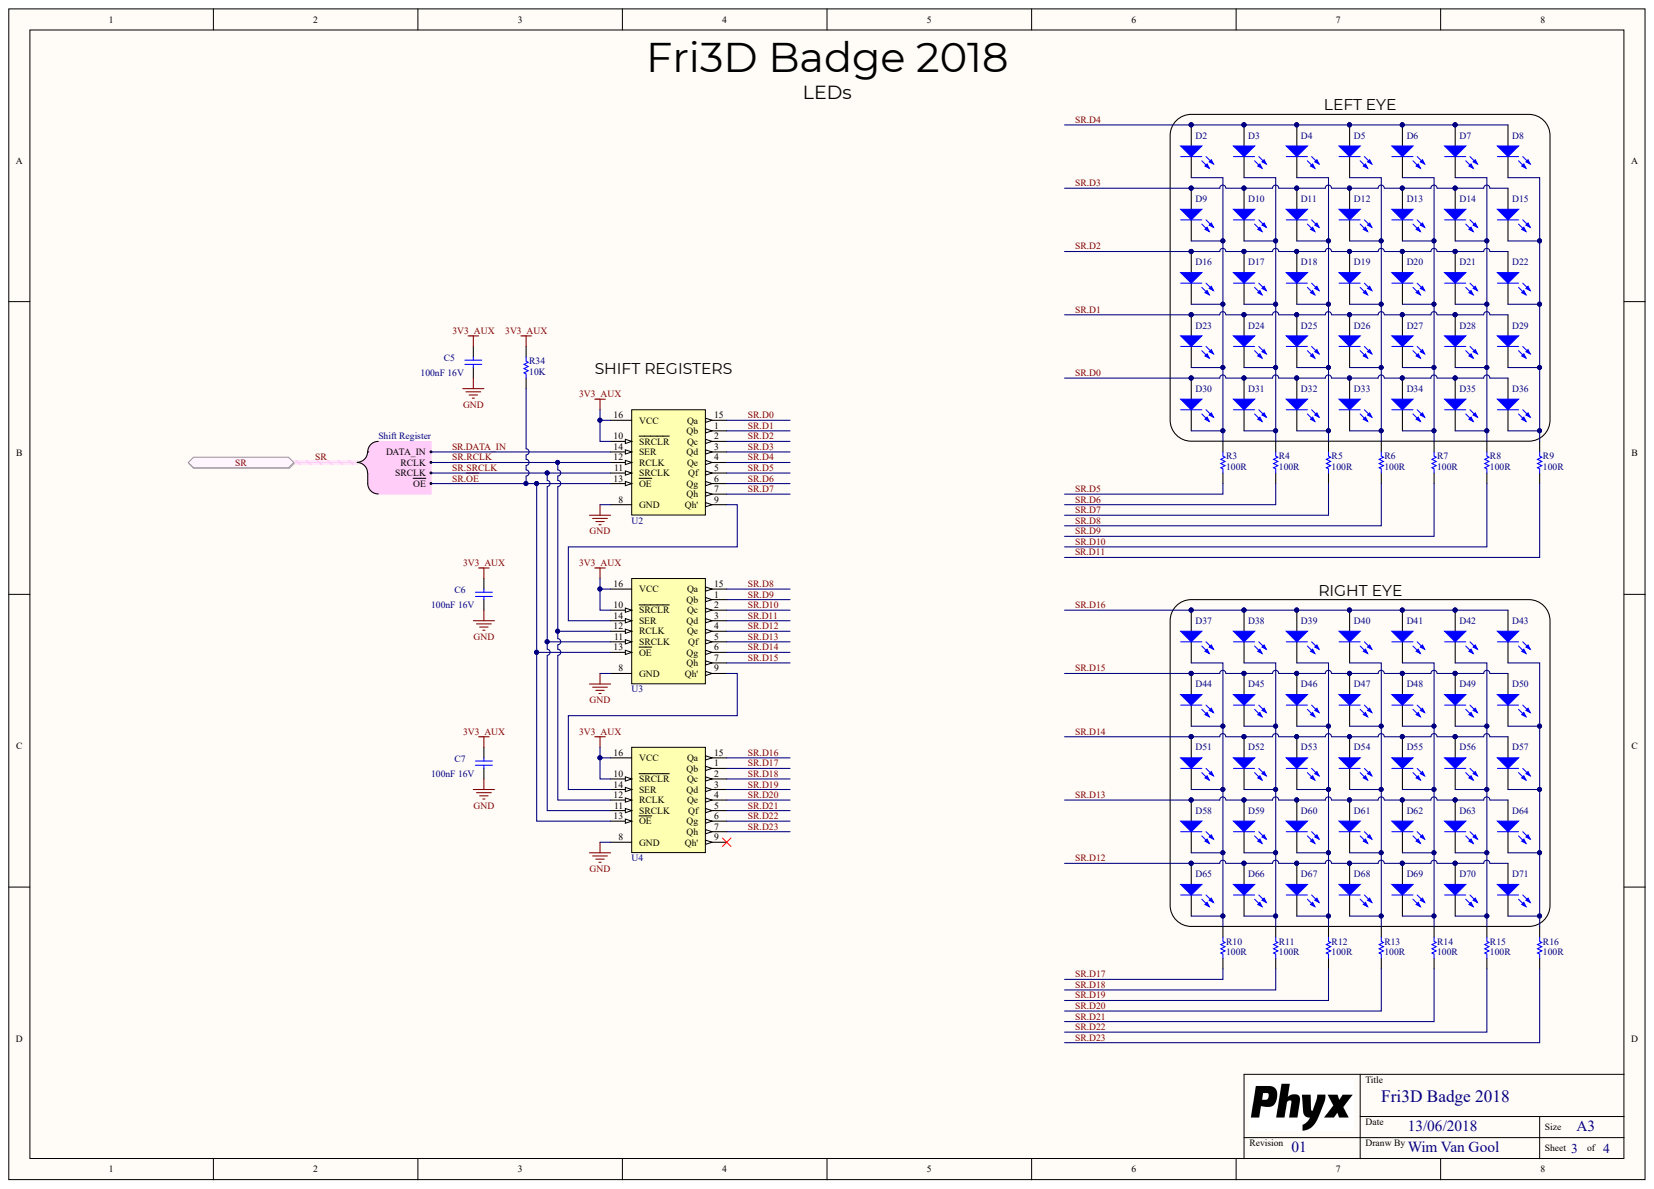
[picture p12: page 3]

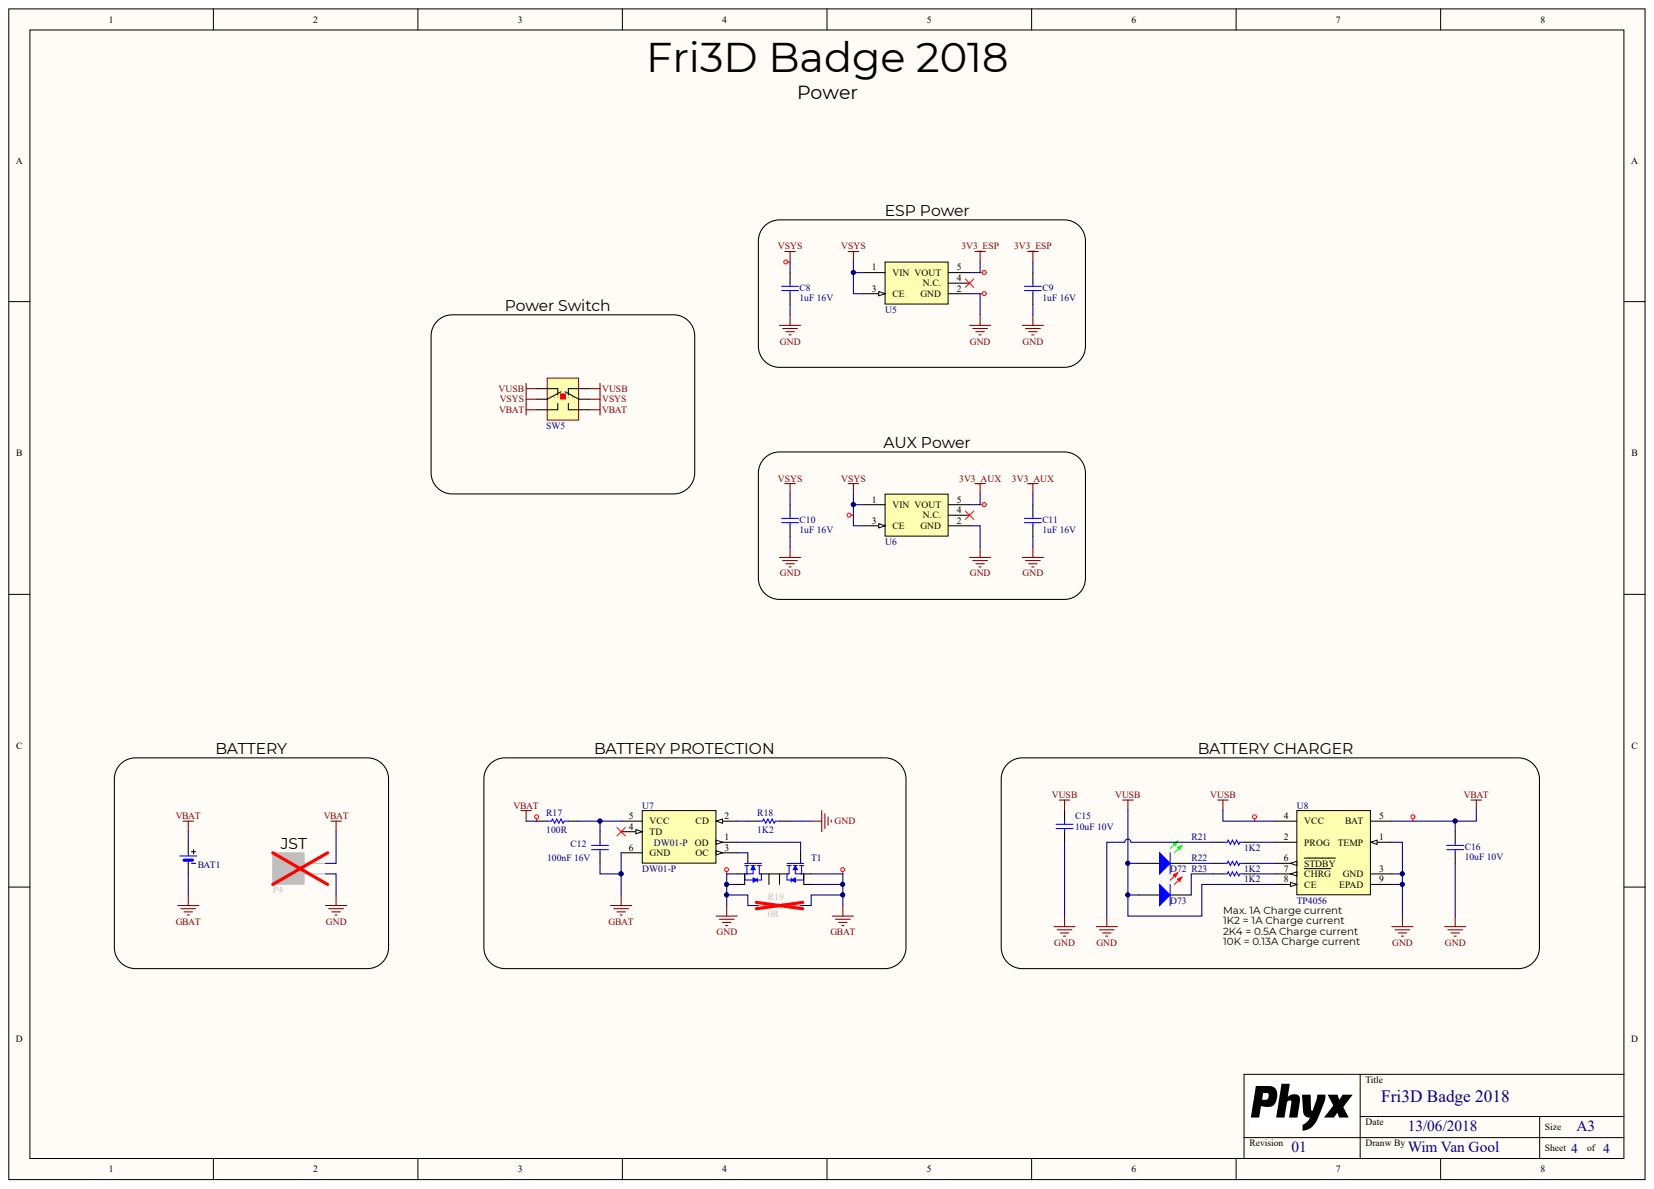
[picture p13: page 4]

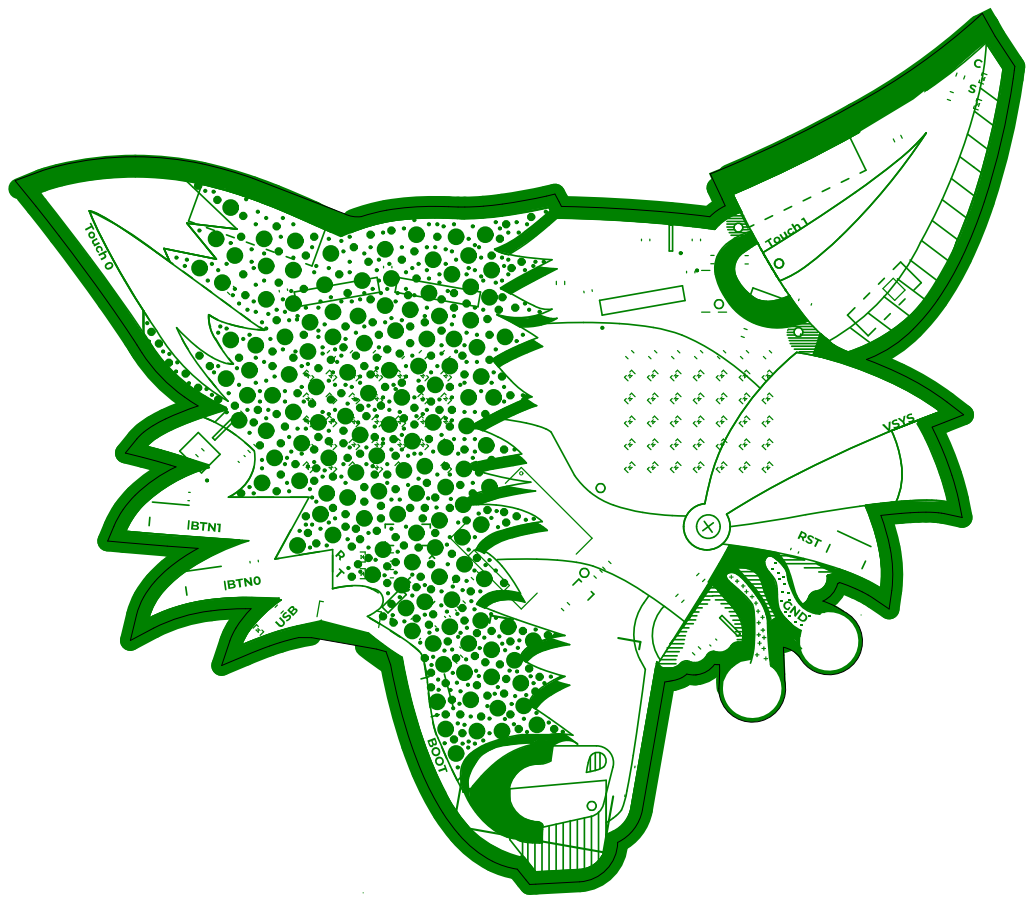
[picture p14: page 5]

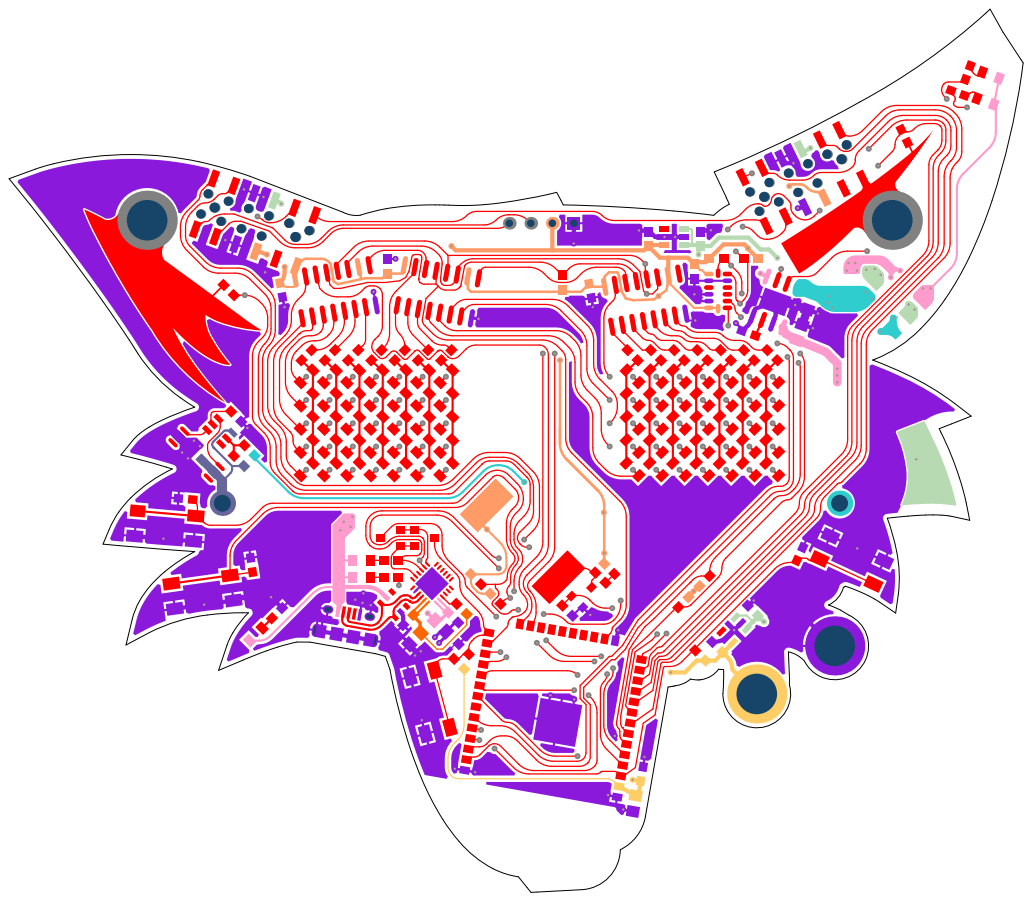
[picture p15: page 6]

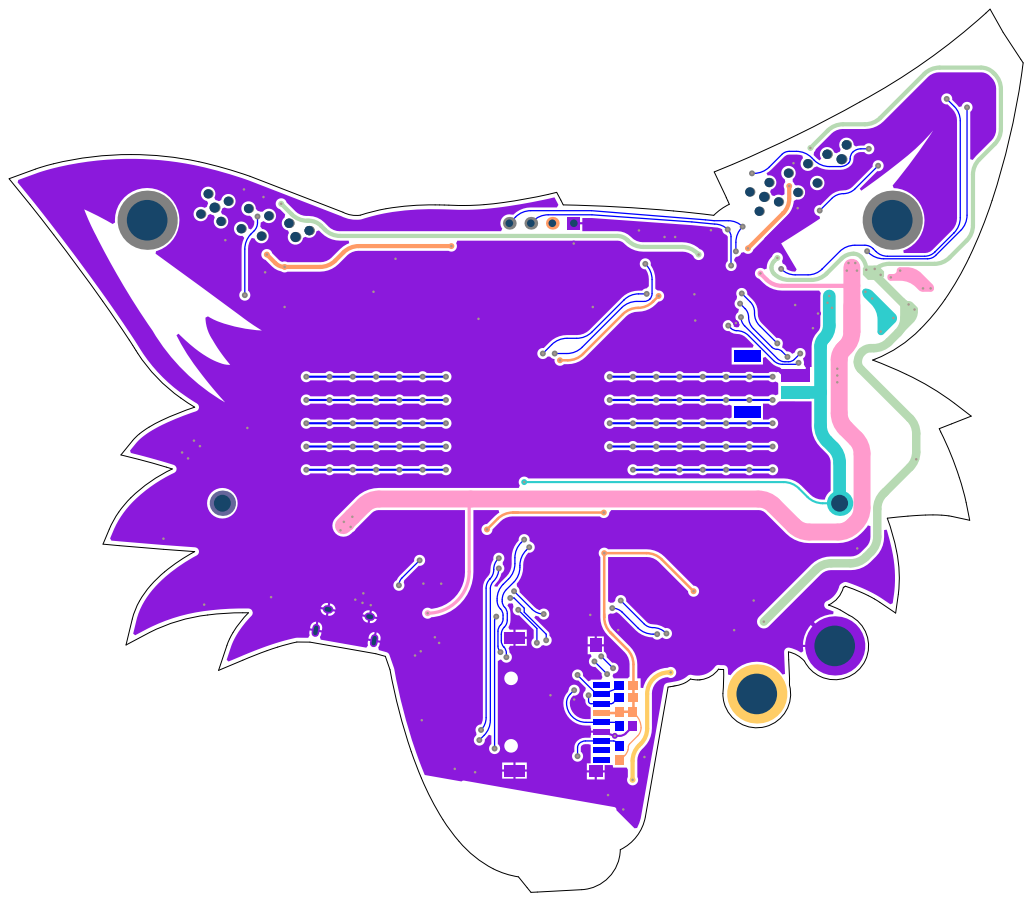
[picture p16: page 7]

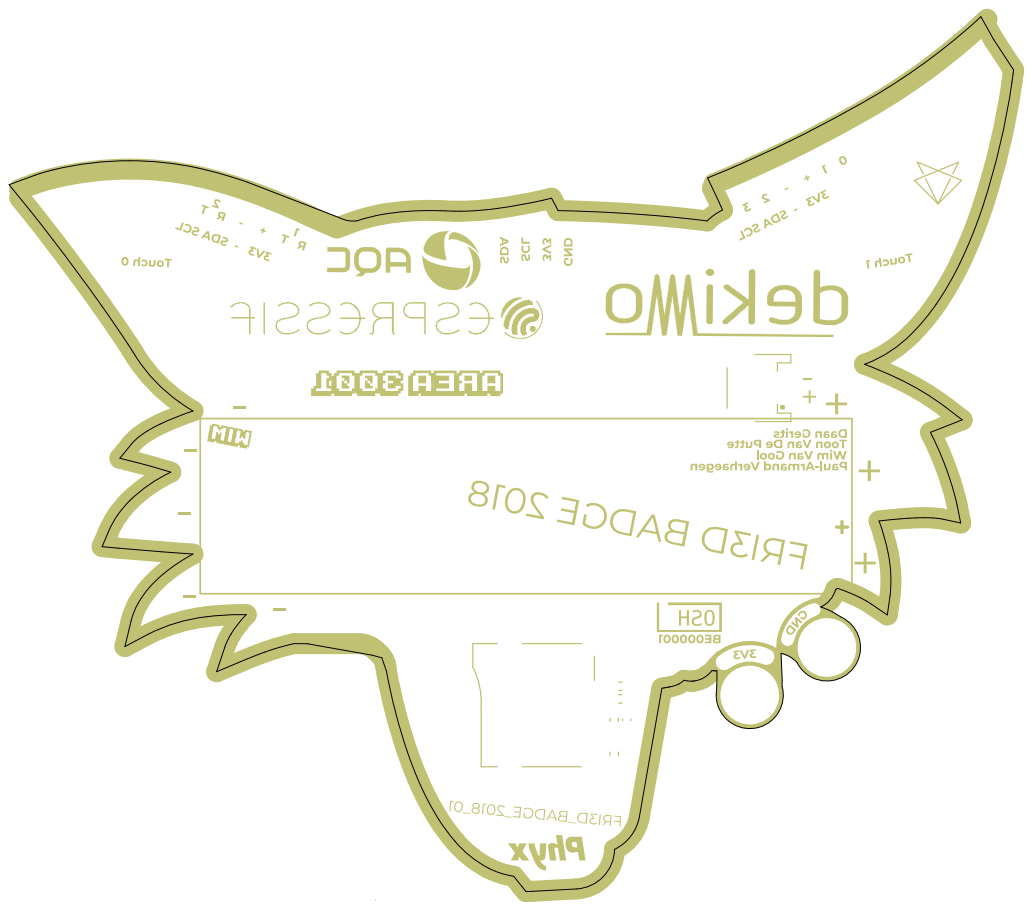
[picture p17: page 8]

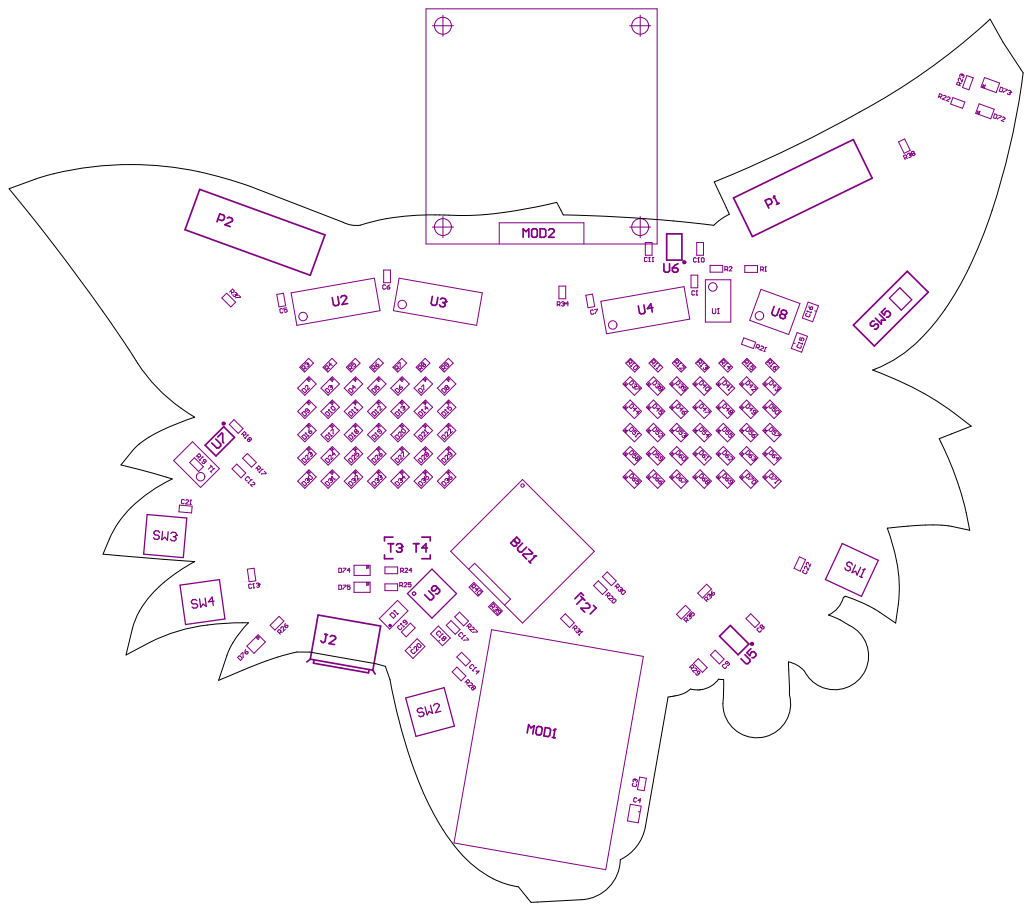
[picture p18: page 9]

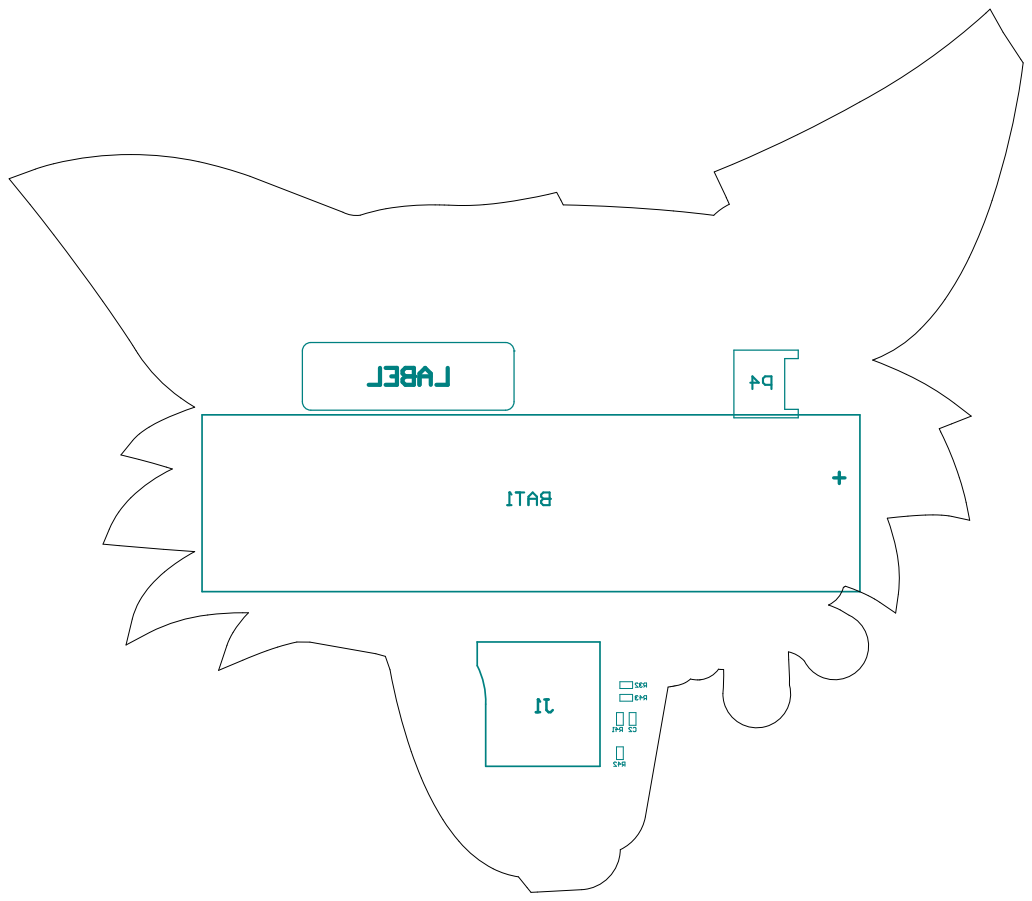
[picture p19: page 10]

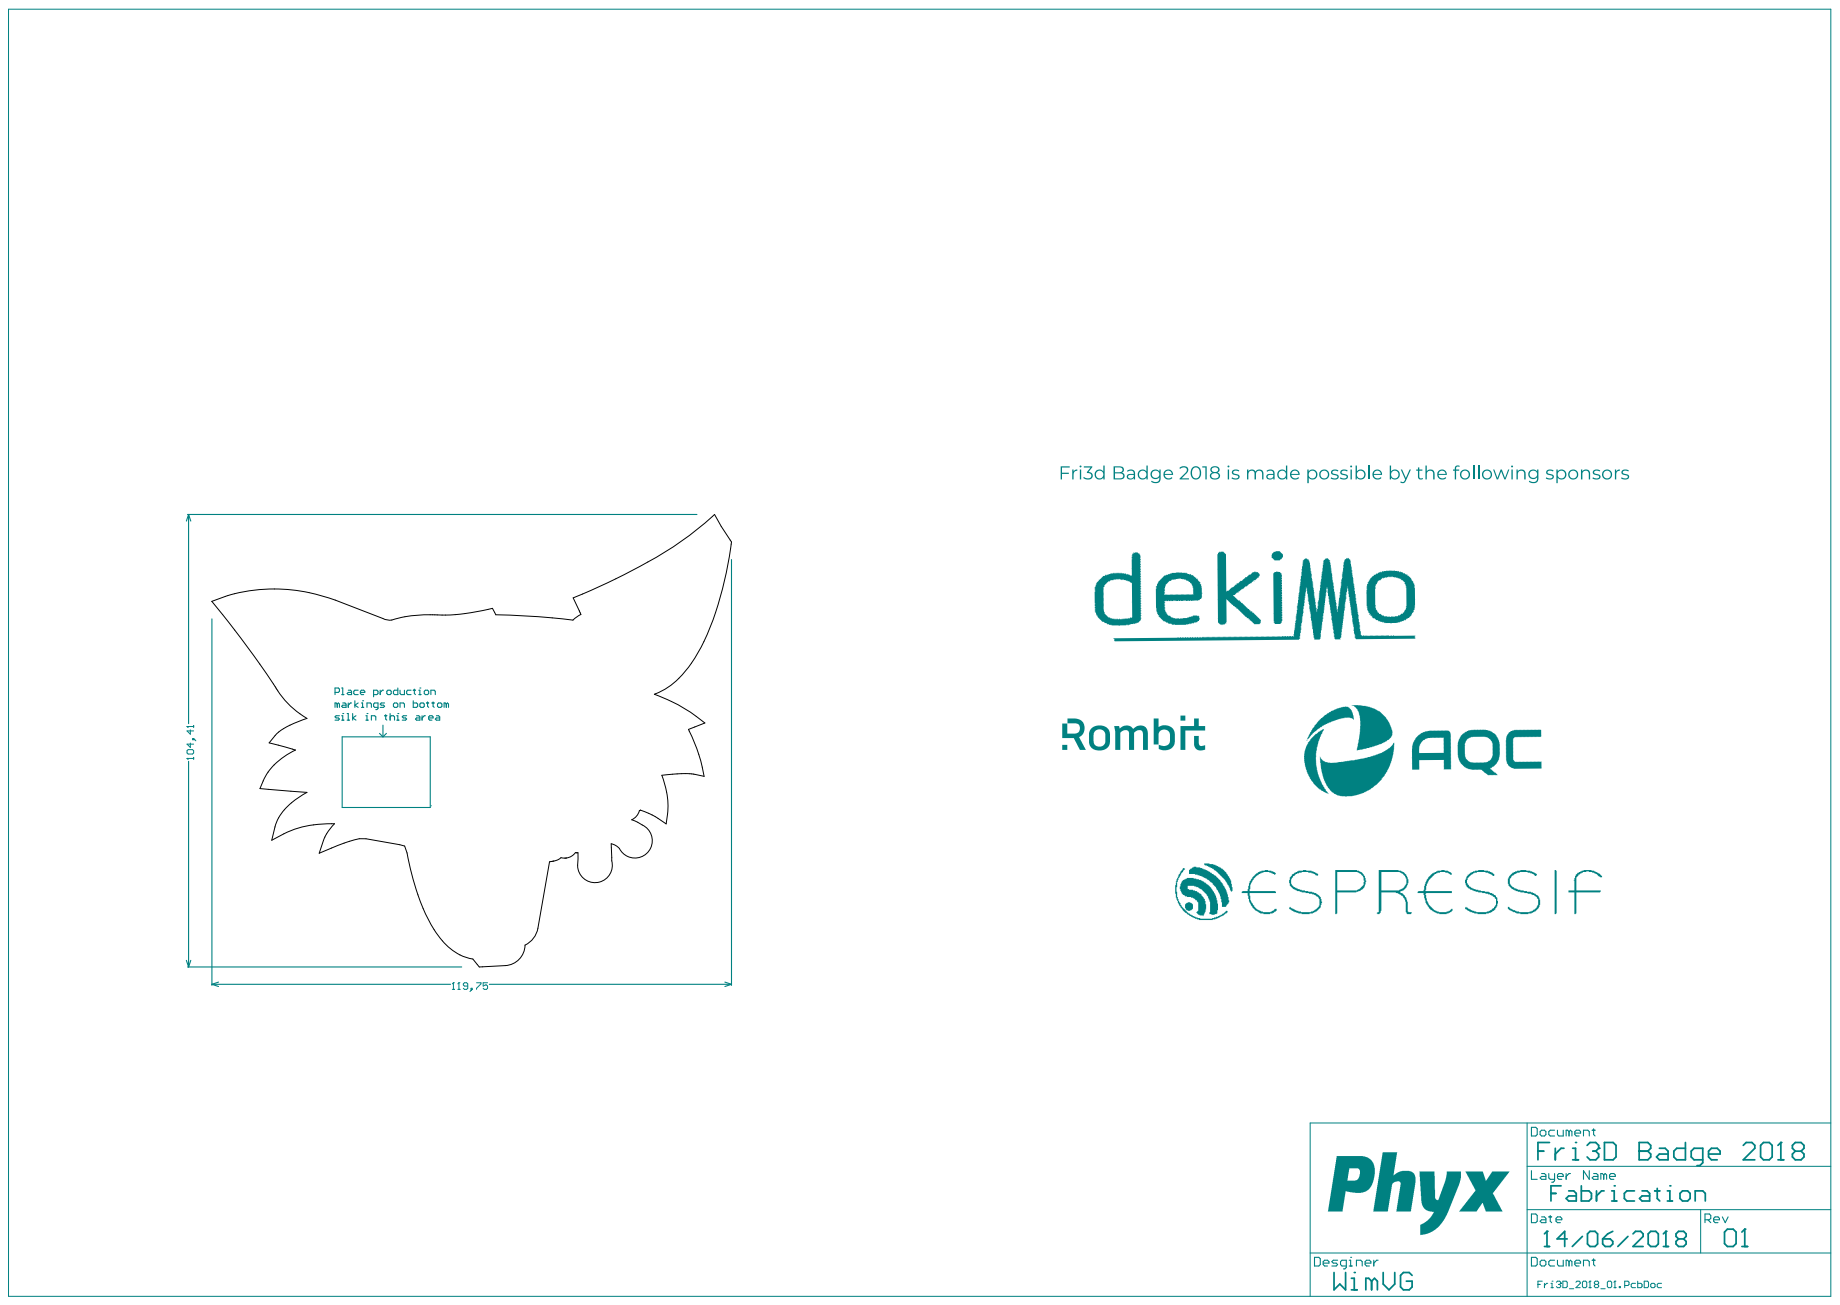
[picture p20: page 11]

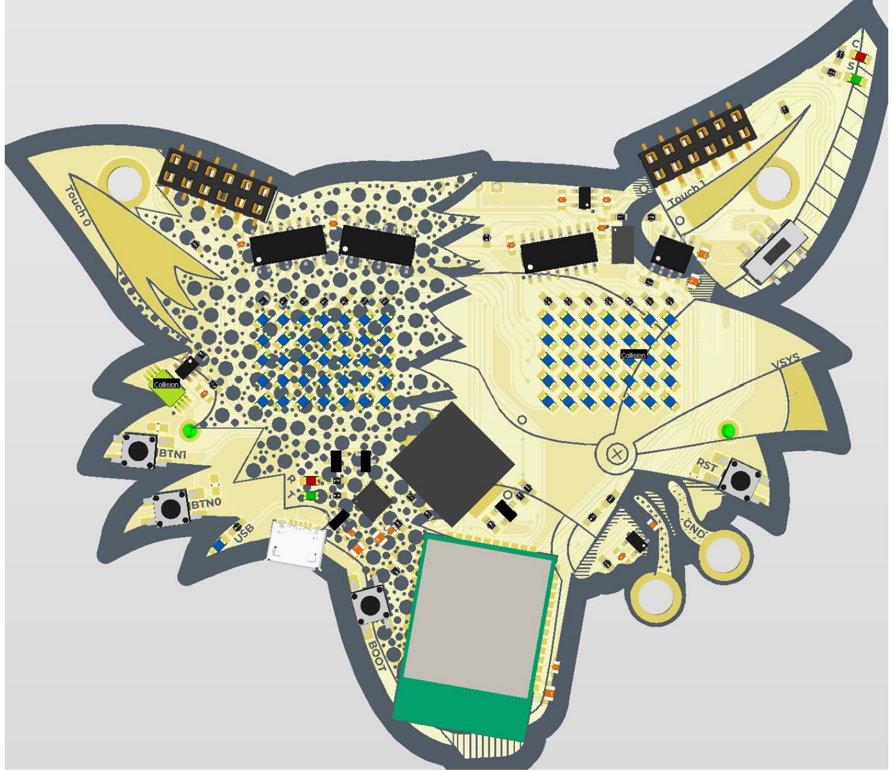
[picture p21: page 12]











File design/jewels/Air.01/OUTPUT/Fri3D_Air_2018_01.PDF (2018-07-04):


Rev. 00 : Initial release
Rev. 01 : Added NeoPixel outputs, optional inductors


















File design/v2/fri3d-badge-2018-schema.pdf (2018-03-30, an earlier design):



MCU | | | ACCELEROMETER LED ARRAY LEFT EYE

LED ARRAY RIGHT EYE

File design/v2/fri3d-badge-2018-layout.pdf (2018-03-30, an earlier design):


10K
R32 | | PTR1B1,27

PTR1B1,27 | | 0

PTR1B1,27

PTR1B1,27 47pF

R10

47pF C9
0.1uF

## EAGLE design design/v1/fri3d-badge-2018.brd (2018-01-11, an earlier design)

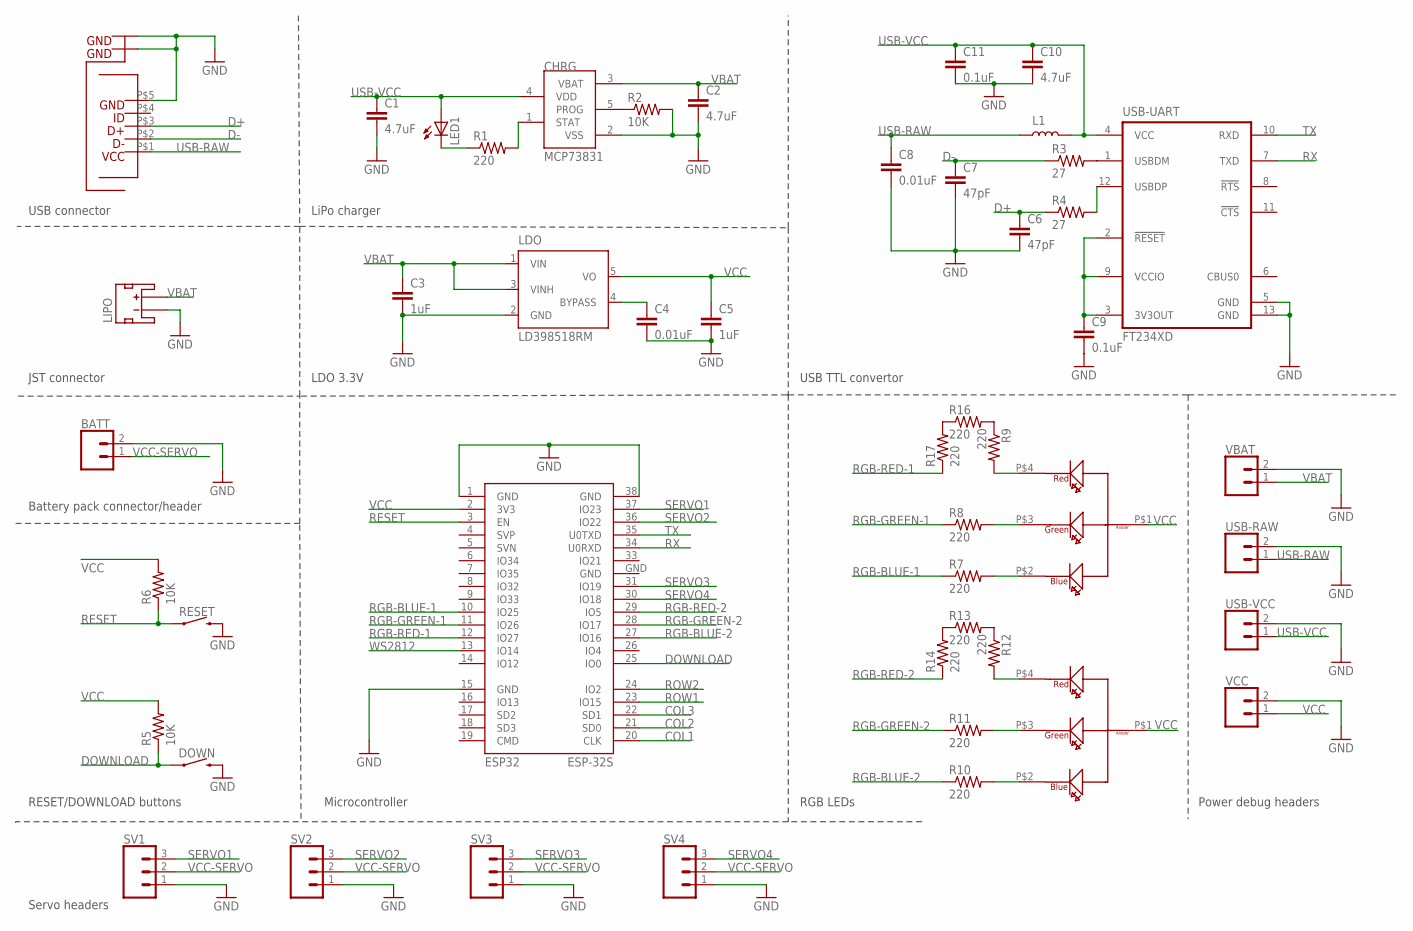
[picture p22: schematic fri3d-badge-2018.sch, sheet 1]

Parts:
BATT: CONN_02; 1X02
C1, C2, C10: 4.7uF; 0805
C3, C5: 1uF; 0805
C4, C8: 0.01uF; 0805
C6, C7: 47pF; 0805
C9, C11: 0.1uF; 0805
CHRG: MCP73831; SOT23-5L
DOWN: MOMENTARY-SWITCH-SPST-PTH-6.0MM; TACTILE_SWITCH_PTH_6.0MM
ESP32: ESP-32S
L1: INDUCTOR-0805-3.3UH; 0805
LDO: LD398518RM; SOT23-5L
LED1: LEDCHIP-LED0805; CHIP-LED0805
LIPO: JST_2MM_MALE; JST-2-SMD
R1, R7, R8, R9, R10, R11, R12, R13, R14, R16, R17: 220; 0805
R2, R5, R6: 10K; 0805
R3, R4: 27; 0805
RESET: MOMENTARY-SWITCH-SPST-PTH-6.0MM; TACTILE_SWITCH_PTH_6.0MM
SV1, SV2, SV3, SV4: CONN_03; 1X03
U$1, U$4: DRAGAN-PERSONAL_AVAGO-RGB-LED
U$5: OCTA-CORE_MCIRO-USB2MOUSER; OCTA-CORE_MICRO-USB2
USB-RAW: CONN_02; 1X02
USB-UART: FT234XD; DFN12
USB-VCC: CONN_02; 1X02
VBAT: CONN_02; 1X02
VCC: CONN_02; 1X02

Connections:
COL1: ESP32.20 (CLK); also elsewhere on the board
COL2: ESP32.21 (SD0); also elsewhere on the board
COL3: ESP32.22 (SD1); also elsewhere on the board
D+: C6.1, R4.1, U$5.P$3
D-: C7.1, R3.1, U$5.P$2
DOWNLOAD: DOWN.1, ESP32.25 (IO0), R5.1
GND: BATT.2, C1.2, C2.2, C3.2, C4.2, C5.2, C6.2, C7.2, C8.2, C9.2, C10.2, C11.2, CHRG.2 (VSS), DOWN.3 (2), ESP32.1 (GND), ESP32.15 (GND), ESP32.38 (GND), ESP32.GND, LDO.2 (GND), LIPO.1 (-), R2.2, RESET.3 (2), SV1.1, SV2.1, SV3.1, SV4.1, U$5.P$5, U$5.P$6, U$5.P$7, U$5.P$8, U$5.P$9, U$5.P$10, U$5.P$11, U$5.P$12, U$5.P$13, USB-RAW.2, USB-UART.5 (GND), USB-UART.13 (GND), USB-VCC.2, VBAT.2, VCC.2; also elsewhere on the board
unnamed: CHRG.5 (PROG), R2.1
unnamed: R3.2, USB-UART.1 (USBDM)
unnamed: CHRG.1 (STAT), R1.2
unnamed: LED1.C, R1.1
unnamed: R4.2, USB-UART.12 (USBDP)
unnamed: C9.1, USB-UART.2 (!RESET!), USB-UART.3 (3V3OUT), USB-UART.9 (VCCIO)
unnamed: C4.1, LDO.4 (BYPASS)
unnamed: R12.1, R13.2
unnamed: R13.1, R14.2
unnamed: R11.2, U$1.P$3
unnamed: R9.1, R16.2
unnamed: R16.1, R17.2
unnamed: R12.2, U$1.P$4
unnamed: R10.2, U$1.P$2
unnamed: R9.2, U$4.P$4
unnamed: R8.2, U$4.P$3
unnamed: R7.2, U$4.P$2
RESET: ESP32.3 (EN), R6.1, RESET.1
RGB-BLUE-1: ESP32.10 (IO25), R7.1
RGB-BLUE-2: ESP32.27 (IO16), R10.1
RGB-GREEN-1: ESP32.11 (IO26), R8.1
RGB-GREEN-2: ESP32.28 (IO17), R11.1
RGB-RED-1: ESP32.12 (IO27), R17.1
RGB-RED-2: ESP32.29 (IO5), R14.1
ROW1: ESP32.23 (IO15); also elsewhere on the board
ROW2: ESP32.24 (IO2); also elsewhere on the board
RX: ESP32.34 (U0RXD), USB-UART.7 (TXD)
SERVO1: ESP32.37 (IO23), SV1.3
SERVO2: ESP32.36 (IO22), SV2.3
SERVO3: ESP32.31 (IO19), SV3.3
SERVO4: ESP32.30 (IO18), SV4.3
TX: ESP32.35 (U0TXD), USB-UART.10 (RXD)
USB-RAW: C8.1, L1.1, U$5.P$1, USB-RAW.1
USB-VCC: C1.1, C10.1, C11.1, CHRG.4 (VDD), L1.2, LED1.A, USB-UART.4 (VCC), USB-VCC.1
VBAT: C2.1, C3.1, CHRG.3 (VBAT), LDO.1 (VIN), LDO.3 (VINH), LIPO.2 (+), VBAT.1
VCC: C5.1, ESP32.2 (3V3), LDO.5 (VO), R5.2, R6.2, U$1.P$1, U$4.P$1, VCC.1; also elsewhere on the board
VCC-SERVO: BATT.1, SV1.2, SV2.2, SV3.2, SV4.2
WS2812: ESP32.13 (IO14); also elsewhere on the board

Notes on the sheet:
USB connector
LiPo charger
USB TTL convertor
LDO 3.3V
JST connector
RESET/DOWNLOAD buttons
Microcontroller
RGB LEDs
Servo headers
Power debug headers
Battery pack connector/header

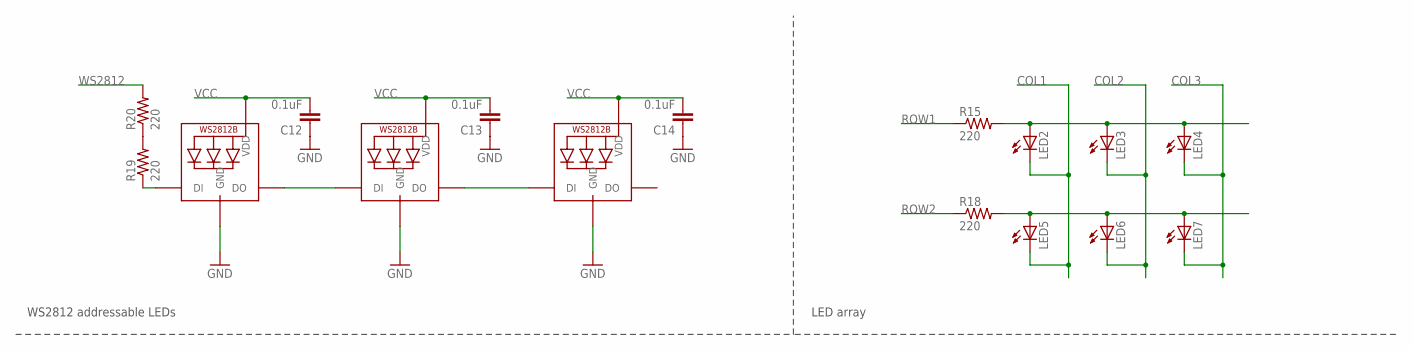
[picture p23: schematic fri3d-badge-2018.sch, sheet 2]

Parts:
C12, C13, C14: 0.1uF; 0805
LED2, LED3, LED4, LED5, LED6, LED7: LEDCHIP-LED0805; CHIP-LED0805
R15, R18, R19, R20: 220; 0805
WS1, WS2, WS3: WS2812B5050; WS2812B

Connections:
COL1: LED2.C, LED5.C; also elsewhere on the board
COL2: LED3.C, LED6.C; also elsewhere on the board
COL3: LED4.C, LED7.C; also elsewhere on the board
GND: C12.1, C13.1, C14.1, WS1.3-GND (GND), WS2.3-GND (GND), WS3.3-GND (GND); also elsewhere on the board
unnamed: WS1.2-DOUT (DO), WS2.4-DIN (DI)
unnamed: WS2.2-DOUT (DO), WS3.4-DIN (DI)
unnamed: LED2.A, LED3.A, LED4.A, R15.2
unnamed: LED5.A, LED6.A, LED7.A, R18.2
unnamed: R19.1, WS1.4-DIN (DI)
unnamed: R19.2, R20.1
ROW1: R15.1; also elsewhere on the board
ROW2: R18.1; also elsewhere on the board
VCC: C12.2, C13.2, C14.2, WS1.1-VDD (VDD), WS2.1-VDD (VDD), WS3.1-VDD (VDD); also elsewhere on the board
WS2812: R20.2; also elsewhere on the board

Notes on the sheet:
WS2812 addressable LEDs
LED array

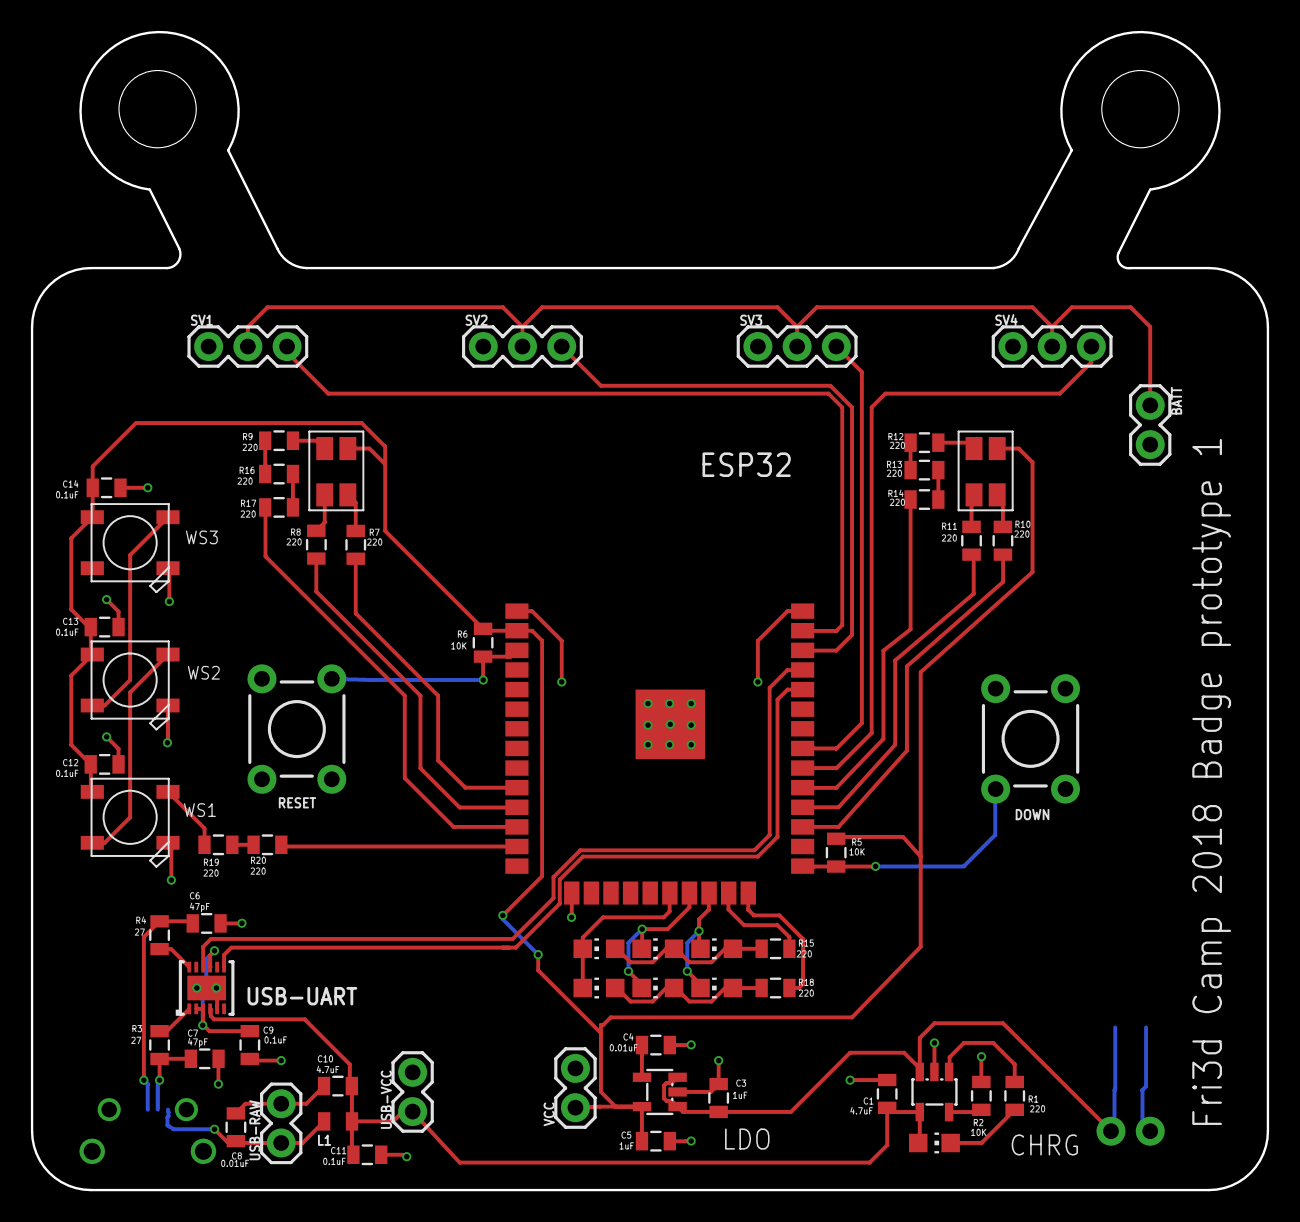
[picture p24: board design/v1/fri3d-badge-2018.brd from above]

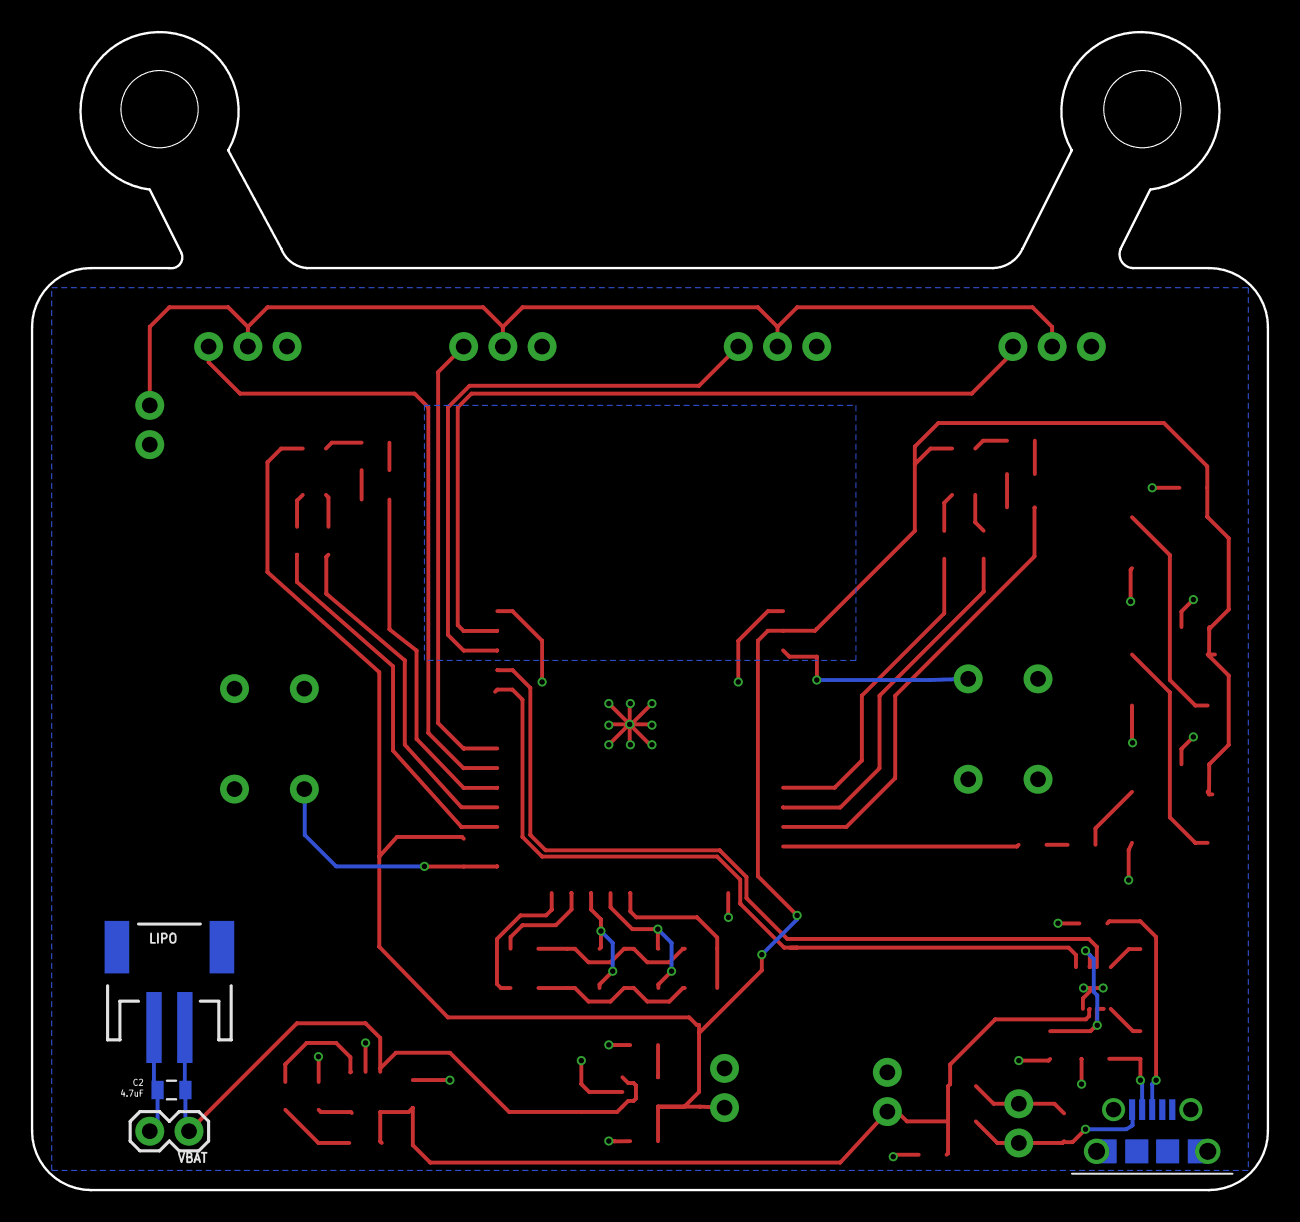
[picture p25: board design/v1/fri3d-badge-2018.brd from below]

Board: 2 copper layers, 80.0 x 75.0 mm, 64 parts (4 on the bottom side), 51 nets.

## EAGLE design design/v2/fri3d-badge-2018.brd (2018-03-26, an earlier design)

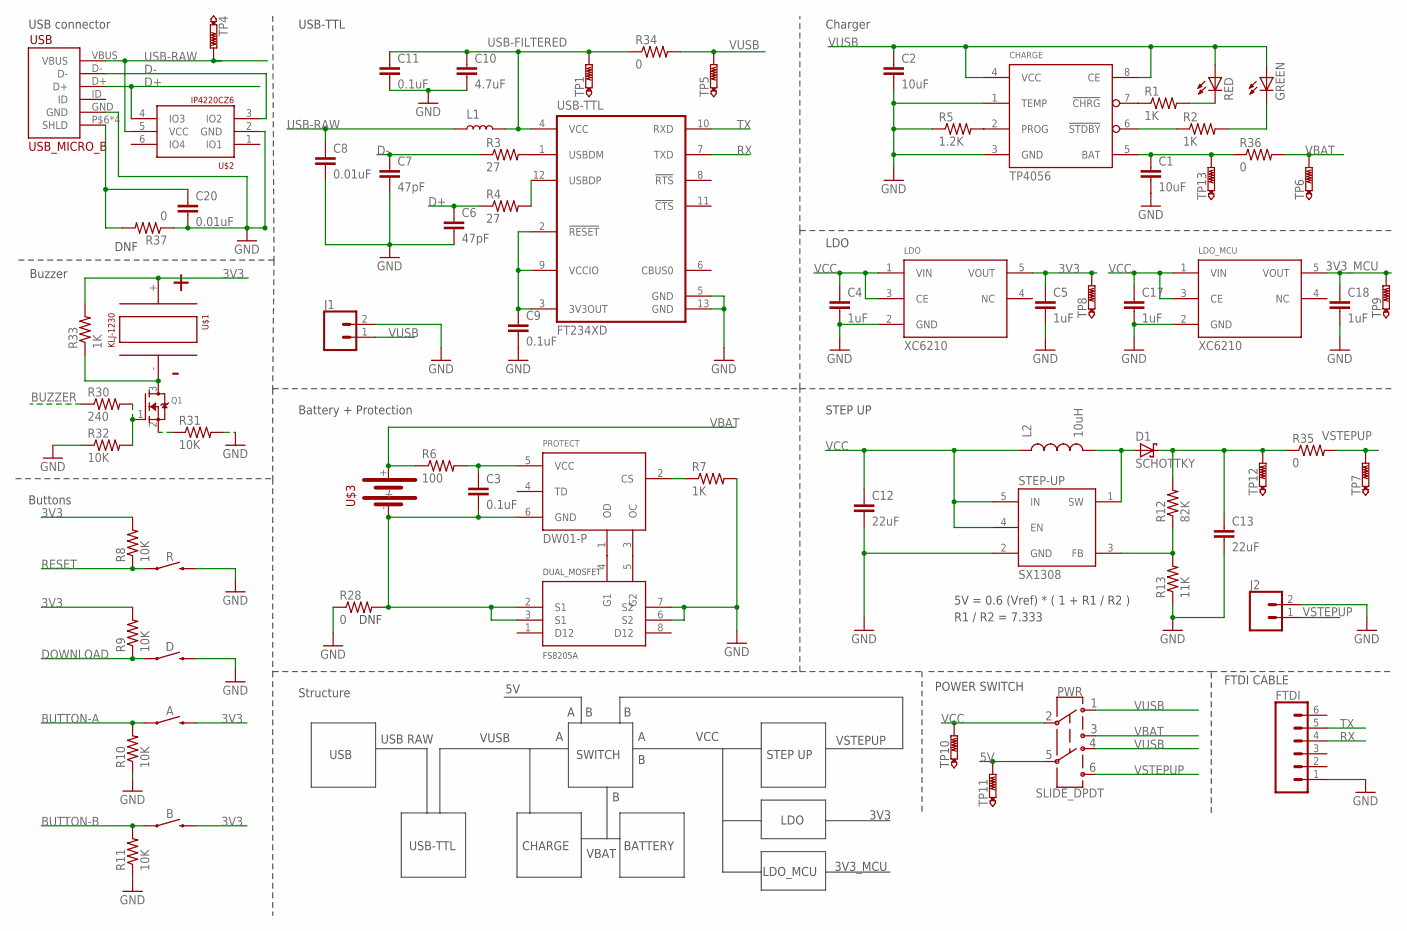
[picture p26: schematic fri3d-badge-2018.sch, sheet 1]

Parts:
A: SWITCH-MOMENTARY-4.5MM
B: SWITCH-MOMENTARY-4.5MM
C1, C2: 10uF; 0805
C3, C9, C11: 0.1uF; 0805
C4, C5, C17, C18: 1uF; 0805
C6, C7: 47pF; 0805
C8, C20: 0.01uF; 0805
C10: 4.7uF; 0805
C12, C13: 22uF; 0805
CHARGE: TP4056; SO8
D: SWITCH-MOMENTARY-4.5MM
D1: SCHOTTKY; SOD993
DUAL_MOSFET: FS8205A; TSSOP8
FTDI: CONN_06SILK_FEMALE_PTH; 1X06
GREEN: LEDCHIP-LED0805; CHIP-LED0805
J1, J2: CONN_02; 1X02
L1: INDUCTOR-0805-3.3UH; 0805
L2: 10uH; TYS6045
LDO: XC6210; SOT23-5
LDO_MCU: XC6210; SOT23-5
PROTECT: DW01-P; SOT23-6
PWR: SLIDE_DPDT; SLIDE_SWITCH
Q1: MOSFET-NREFLOW; SOT23
R: SWITCH-MOMENTARY-4.5MM
R1, R2, R7, R33: 1K; 0805
R3, R4: 27; 0805
R5: 1.2K; 0805
R6: 100; 0805
R8, R9, R10, R11, R31, R32: 10K; 0805
R12: 82K; 0805
R13: 11K; 0805
R28, R34, R35, R36, R37: 0; 0805
R30: 240; 0805
RED: LEDCHIP-LED0805; CHIP-LED0805
STEP-UP: SX1308; SOT23-6
TP1, TP4, TP5, TP6, TP7, TP8, TP9, TP10, TP11, TP12, TP13: PTR1B1,27; B1,27
U$1: KLJ-1230
U$2: IP4220CZ6; SOT457R_PHILIPS
U$3: CR18650; BATTERY_HOLDER_18650
USB: USB_MICRO_B
USB-TTL: FT234XD; DFN12

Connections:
3V3: A.3 (2), A.4 (2), B.3 (2), B.4 (2), C5.1, LDO.5 (VOUT), R8.2, R9.2, R33.2, TP8.TP, U$1.+; also elsewhere on the board
3V3_MCU: C18.1, LDO_MCU.5 (VOUT), TP9.TP; also elsewhere on the board
5V: PWR.5, TP11.TP; also elsewhere on the board
BUTTON-A: A.1, A.2 (1), R10.2; also elsewhere on the board
BUTTON-B: B.1, B.2 (1), R11.2; also elsewhere on the board
BUZZER: R30.1; also elsewhere on the board
D+: C6.1, R4.1, U$2.4 (IO3), USB.D+
D-: C7.1, R3.1, U$2.3 (IO2), USB.D-
DOWNLOAD: D.1, D.2 (1), R9.1; also elsewhere on the board
GND: C1.2, C2.2, C4.2, C5.2, C6.2, C7.2, C8.2, C9.2, C10.2, C11.2, C12.2, C13.2, C17.2, C18.2, C20.2, CHARGE.1 (TEMP), CHARGE.3 (GND), D.3 (2), D.4 (2), DUAL_MOSFET.6 (S2), DUAL_MOSFET.7 (S2), FTDI.1, J1.2, J2.2, LDO.2 (GND), LDO_MCU.2 (GND), R.3 (2), R.4 (2), R5.1, R7.2, R10.1, R11.1, R13.1, R28.1, R31.2, R32.1, R37.1, STEP-UP.2 (GND), U$2.2 (GND), USB.GND, USB-TTL.5 (GND), USB-TTL.13 (GND); also elsewhere on the board
unnamed: C13.1, D1.P$2 (C), R12.2, R35.1, TP12.TP
unnamed: Q1.3 (D), R33.1, U$1.-
unnamed: R3.2, USB-TTL.1 (USBDM)
unnamed: CHARGE.7 (!CHRG!), R1.1
unnamed: R4.2, USB-TTL.12 (USBDP)
unnamed: C9.1, USB-TTL.2 (!RESET!), USB-TTL.3 (3V3OUT), USB-TTL.9 (VCCIO)
unnamed: CHARGE.6 (!STDBY!), R2.1
unnamed: R1.2, RED.C
unnamed: GREEN.C, R2.2
unnamed: CHARGE.2 (PROG), R5.2
unnamed: Q1.1 (G), R30.2, R32.2
unnamed: PROTECT.2 (CS), R7.1
unnamed: C3.1, PROTECT.5 (VCC), R6.2
unnamed: DUAL_MOSFET.4 (G1), PROTECT.1 (OD)
unnamed: DUAL_MOSFET.5 (G2), PROTECT.3 (OC)
unnamed: R12.1, R13.2, STEP-UP.3 (FB)
unnamed: D1.P$1 (A), L2.P$2 (2), STEP-UP.1 (SW)
unnamed: C1.1, CHARGE.5 (BAT), R36.1, TP13.TP
unnamed: C20.1, R37.2, USB.P$6 (SHLD), USB.P$7 (SHLD), USB.P$8 (SHLD), USB.P$9 (SHLD)
unnamed: C3.2, DUAL_MOSFET.2 (S1), DUAL_MOSFET.3 (S1), PROTECT.6 (GND), R28.2, U$3.-
unnamed: Q1.2 (S), R31.1
RESET: R.1, R.2 (1), R8.1; also elsewhere on the board
RX: FTDI.4, USB-TTL.7 (TXD); also elsewhere on the board
TX: FTDI.5, USB-TTL.10 (RXD); also elsewhere on the board
USB-FILTERED: C10.1, C11.1, L1.2, R34.1, TP1.TP, USB-TTL.4 (VCC)
USB-RAW: C8.1, L1.1, TP4.TP, U$2.5 (VCC), USB.VBUS
VBAT: PWR.3, R6.1, R36.2, TP6.TP, U$3.+
VCC: C4.1, C12.1, C17.1, L2.P$1 (1), LDO.1 (VIN), LDO.3 (CE), LDO_MCU.1 (VIN), LDO_MCU.3 (CE), PWR.2, STEP-UP.4 (EN), STEP-UP.5 (IN), TP10.TP
VSTEPUP: J2.1, PWR.4 (6), R35.2, TP7.TP
VUSB: C2.1, CHARGE.4 (VCC), CHARGE.8 (CE), GREEN.A, J1.1, PWR.1, PWR.8 (4), R34.2, RED.A, TP5.TP

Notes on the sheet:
USB connector
Charger
USB-TTL
Battery + Protection
LDO
POWER SWITCH
Buttons
STEP UP
USB
USB RAW
VUSB
CHARGE
VBAT
BATTERY
Structure
VCC
SWITCH
3V3
VSTEPUP
5V = 0.6 (Vref) * ( 1 + R1 / R2 )
R1 / R2 = 7.333
DNF
FTDI CABLE
LDO_MCU
3V3_MCU
Buzzer

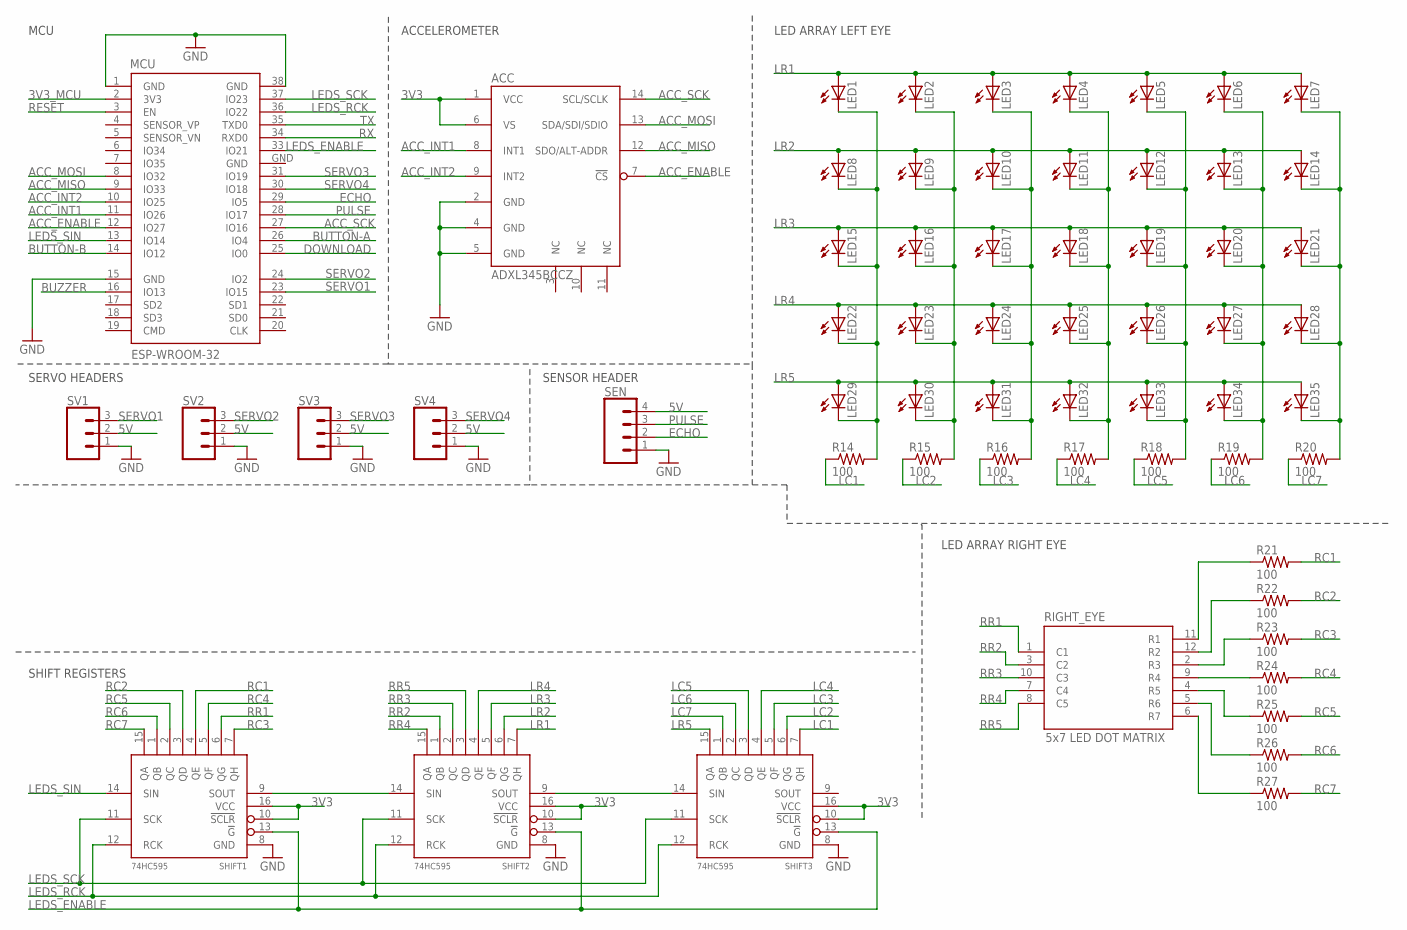
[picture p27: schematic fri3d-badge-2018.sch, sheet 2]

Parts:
ACC: ADXL345BCCZ; LGA
LED1, LED2, LED3, LED4, LED5, LED6, LED7, LED8, LED9, LED10, LED11, LED12, LED13, LED14, LED15, LED16, LED17, LED18, LED19, LED20, LED21, LED22, LED23, LED24, LED25, LED26, LED27, LED28, LED29, LED30, LED31, LED32, LED33, LED34, LED35: LEDCHIP-LED0805; CHIP-LED0805
MCU: ESP-WROOM-32
R14, R15, R16, R17, R18, R19, R20, R21, R22, R23, R24, R25, R26, R27: 100; 0805
RIGHT_EYE: 5x7 LED DOT MATRIX; 5X7_DOT_LED_MATRIX
SEN: CONN_04; 1X04
SHIFT1, SHIFT2, SHIFT3: 74HC595; SO16
SV1, SV2, SV3, SV4: CONN_03; 1X03

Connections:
3V3: ACC.1 (VCC), ACC.6 (VS), SHIFT1.10 (!SCLR), SHIFT1.16 (VCC), SHIFT2.10 (!SCLR), SHIFT2.16 (VCC), SHIFT3.10 (!SCLR), SHIFT3.16 (VCC); also elsewhere on the board
3V3_MCU: MCU.2 (3V3); also elsewhere on the board
5V: SEN.4, SV1.2, SV2.2, SV3.2, SV4.2; also elsewhere on the board
ACC_ENABLE: ACC.7 (!CS!), MCU.12 (IO27)
ACC_INT1: ACC.8 (INT1), MCU.11 (IO26)
ACC_INT2: ACC.9 (INT2), MCU.10 (IO25)
ACC_MISO: ACC.12 (SDO/ALT-ADDR), MCU.9 (IO33)
ACC_MOSI: ACC.13 (SDA/SDI/SDIO), MCU.8 (IO32)
ACC_SCK: ACC.14 (SCL/SCLK), MCU.27 (IO16)
BUTTON-A: MCU.26 (IO4); also elsewhere on the board
BUTTON-B: MCU.14 (IO12); also elsewhere on the board
BUZZER: MCU.16 (IO13); also elsewhere on the board
DOWNLOAD: MCU.25 (IO0); also elsewhere on the board
ECHO: MCU.29 (IO5), SEN.2
GND: ACC.2 (GND), ACC.4 (GND), ACC.5 (GND), MCU.1 (GND), MCU.15 (GND), MCU.38 (GND), MCU.GND, SEN.1, SHIFT1.8 (GND), SHIFT2.8 (GND), SHIFT3.8 (GND), SV1.1, SV2.1, SV3.1, SV4.1; also elsewhere on the board
LC1: R14.1, SHIFT3.7 (QH)
LC2: R15.1, SHIFT3.6 (QG)
LC3: R16.1, SHIFT3.5 (QF)
LC4: R17.1, SHIFT3.4 (QE)
LC5: R18.1, SHIFT3.3 (QD)
LC6: R19.1, SHIFT3.2 (QC)
LC7: R20.1, SHIFT3.1 (QB)
LEDS_ENABLE: MCU.33 (IO21), SHIFT1.13 (!G), SHIFT2.13 (!G), SHIFT3.13 (!G)
LEDS_RCK: MCU.36 (IO22), SHIFT1.12 (RCK), SHIFT2.12 (RCK), SHIFT3.12 (RCK)
LEDS_SCK: MCU.37 (IO23), SHIFT1.11 (SCK), SHIFT2.11 (SCK), SHIFT3.11 (SCK)
LEDS_SIN: MCU.13 (IO14), SHIFT1.14 (SIN)
LR1: LED1.A, LED2.A, LED3.A, LED4.A, LED5.A, LED6.A, LED7.A, SHIFT2.7 (QH)
LR2: LED8.A, LED9.A, LED10.A, LED11.A, LED12.A, LED13.A, LED14.A, SHIFT2.6 (QG)
LR3: LED15.A, LED16.A, LED17.A, LED18.A, LED19.A, LED20.A, LED21.A, SHIFT2.5 (QF)
LR4: LED22.A, LED23.A, LED24.A, LED25.A, LED26.A, LED27.A, LED28.A, SHIFT2.4 (QE)
LR5: LED29.A, LED30.A, LED31.A, LED32.A, LED33.A, LED34.A, LED35.A, SHIFT3.15 (QA)
unnamed: SHIFT1.9 (SOUT), SHIFT2.14 (SIN)
unnamed: SHIFT2.9 (SOUT), SHIFT3.14 (SIN)
unnamed: R21.1, RIGHT_EYE.11 (R1)
unnamed: R22.1, RIGHT_EYE.12 (R2)
unnamed: LED1.C, LED8.C, LED15.C, LED22.C, LED29.C, R14.2
unnamed: LED2.C, LED9.C, LED16.C, LED23.C, LED30.C, R15.2
unnamed: LED3.C, LED10.C, LED17.C, LED24.C, LED31.C, R16.2
unnamed: LED4.C, LED11.C, LED18.C, LED25.C, LED32.C, R17.2
unnamed: LED5.C, LED12.C, LED19.C, LED26.C, LED33.C, R18.2
unnamed: LED6.C, LED13.C, LED20.C, LED27.C, LED34.C, R19.2
unnamed: LED7.C, LED14.C, LED21.C, LED28.C, LED35.C, R20.2
unnamed: R24.1, RIGHT_EYE.9 (R4)
unnamed: R23.1, RIGHT_EYE.2 (R3)
unnamed: R25.1, RIGHT_EYE.4 (R5)
unnamed: R26.1, RIGHT_EYE.5 (R6)
unnamed: R27.1, RIGHT_EYE.6 (R7)
PULSE: MCU.28 (IO17), SEN.3
RC1: R21.2, SHIFT1.4 (QE)
RC2: R22.2, SHIFT1.3 (QD)
RC3: R23.2, SHIFT1.7 (QH)
RC4: R24.2, SHIFT1.5 (QF)
RC5: R25.2, SHIFT1.2 (QC)
RC6: R26.2, SHIFT1.1 (QB)
RC7: R27.2, SHIFT1.15 (QA)
RESET: MCU.3 (EN); also elsewhere on the board
RR1: RIGHT_EYE.1 (C1), SHIFT1.6 (QG)
RR2: RIGHT_EYE.3 (C2), SHIFT2.1 (QB)
RR3: RIGHT_EYE.10 (C3), SHIFT2.2 (QC)
RR4: RIGHT_EYE.7 (C4), SHIFT2.15 (QA)
RR5: RIGHT_EYE.8 (C5), SHIFT2.3 (QD)
RX: MCU.34 (RXD0); also elsewhere on the board
SERVO1: MCU.23 (IO15), SV1.3
SERVO2: MCU.24 (IO2), SV2.3
SERVO3: MCU.31 (IO19), SV3.3
SERVO4: MCU.30 (IO18), SV4.3
TX: MCU.35 (TXD0); also elsewhere on the board

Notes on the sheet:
LED ARRAY LEFT EYE
LED ARRAY RIGHT EYE
SHIFT REGISTERS
MCU
ACCELEROMETER
SERVO HEADERS
SENSOR HEADER

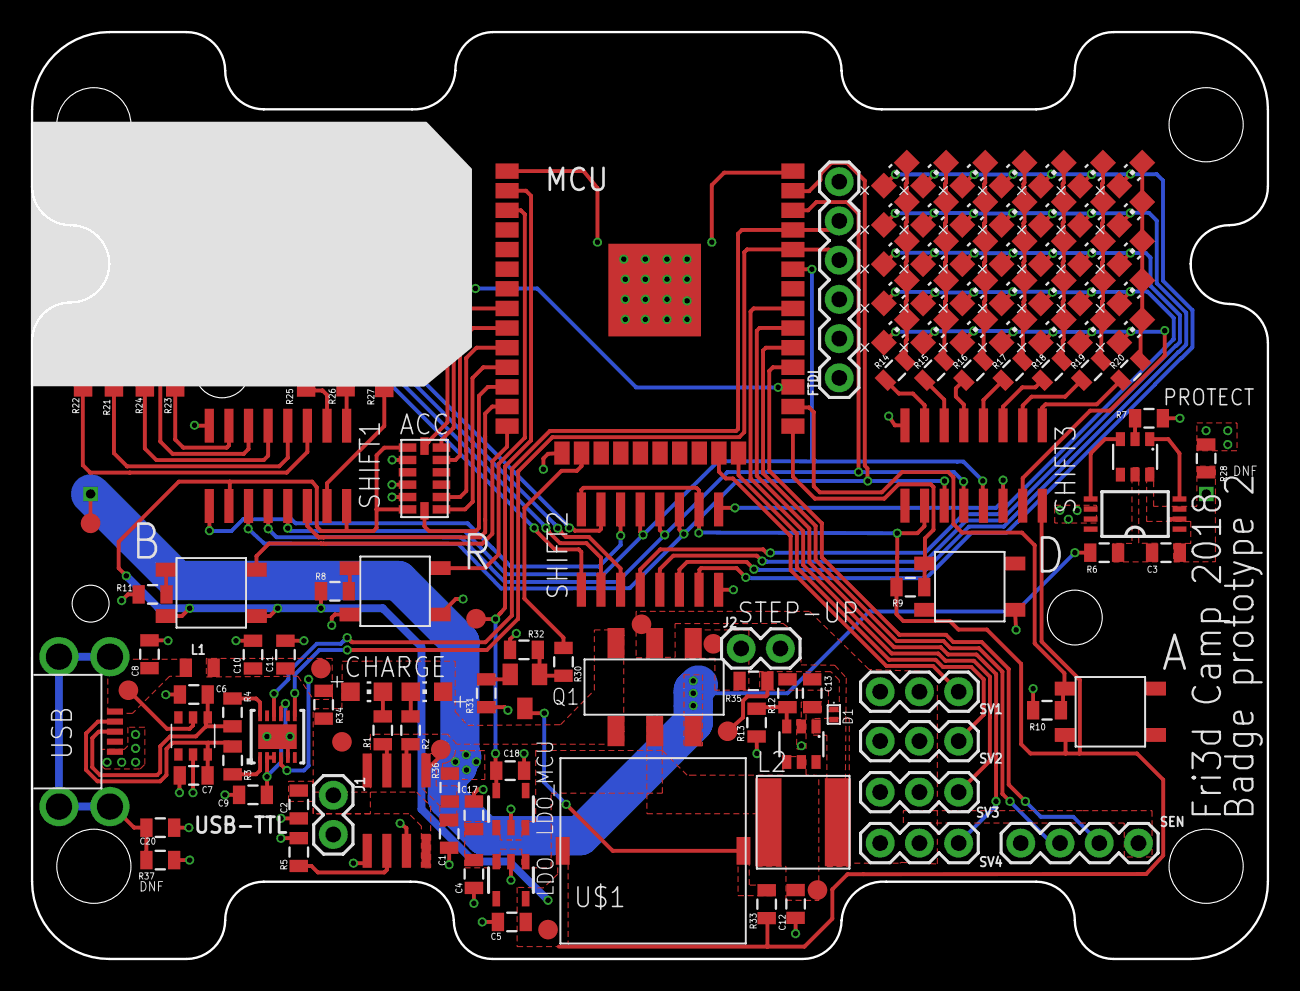
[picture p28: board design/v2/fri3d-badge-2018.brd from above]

Board: 2 copper layers, 80.0 x 60.0 mm, 134 parts (1 on the bottom side), 96 nets.

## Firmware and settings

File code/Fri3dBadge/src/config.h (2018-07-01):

// (hardware) configuratie van de badge

#ifndef __CONFIG_H
#define __CONFIG_H

// Button pinnen

#define BUTTON_A_PIN   12
#define BUTTON_B_PIN    4
#define BUTTON_D_PIN    0

// LED matrix pinnen

#define LED_LATCH_PIN  15
#define LED_CLOCK_PIN  4
#define LED_DATA_PIN   2
#define LED_ENABLE_PIN 13

#define LED_RIGHT_EYE 0
#define LED_LEFT_EYE  1

// Servo pinnen

#define SERVO1_PIN     15
#define SERVO2_PIN      2
#define SERVO3_PIN     19
#define SERVO4_PIN     18

#endif

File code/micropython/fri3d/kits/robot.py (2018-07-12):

from fri3d.jewels.servo_jewel import ServoJewel

import utime

MIN = 60
CENTER = 90
MAX = 120


class Legs:
    def __init__(self, left_hip=1, left_ankle=0, right_hip=2, right_ankle=3):
        self.left_hip = left_hip
        self.left_ankle = left_ankle
        self.right_hip = right_hip
        self.right_ankle = right_ankle

        self.servos = ServoJewel()
        self.servos.center()

# -- Utilities --------------------------------------------------------------------------------------------------------

    def reset(self):
        self.servos.center()

# -- Leaning ----------------------------------------------------------------------------------------------------------

    def lean_to_left(self, speed=ServoJewel.SPEED_MEDIUM):
        self.servos.angle(MIN, speed, self.right_ankle)
        self.servos.angle(MIN, speed, self.left_ankle)

    def lean_to_right(self, speed=ServoJewel.SPEED_MEDIUM):
        self.servos.angle(MAX, speed, self.left_ankle)
        self.servos.angle(MAX, speed, self.right_ankle)

    def undo_lean_to_left(self, speed=ServoJewel.SPEED_SLOW):
        self.servos.angle(CENTER, speed, self.right_ankle)
        self.servos.angle(CENTER, int(speed * 2), self.left_ankle)

    def undo_lean_to_right(self, speed=ServoJewel.SPEED_SLOW):
        self.servos.angle(CENTER, speed, self.left_ankle)
        self.servos.angle(CENTER, int(speed * 2), self.right_ankle)

# -- Twisting ---------------------------------------------------------------------------------------------------------

    def twist_left(self, speed=ServoJewel.SPEED_FAST):
        self._twist(MAX, speed)

    def twist_center(self, speed=ServoJewel.SPEED_FAST):
        self._twist(CENTER, speed)

    def twist_right(self, speed=ServoJewel.SPEED_FAST):
        self._twist(MIN, speed)

    def _twist(self, angle, speed=ServoJewel.SPEED_FAST):
        self.servos.angle(angle, speed, self.right_hip, self.left_hip)

# -- Pointing Feet ----------------------------------------------------------------------------------------------------

    def center_to_front_right(self):
        self.servos.angle(MAX, ServoJewel.SPEED_FAST, self.right_hip, self.left_hip)

    def front_right_to_center(self):
        self.servos.angle(CENTER, ServoJewel.SPEED_FAST, self.right_hip, self.left_hip)

    def center_to_front_left(self):
        self.servos.angle(MIN, ServoJewel.SPEED_FAST, self.right_hip, self.left_hip)

    def front_left_to_center(self):
        self.servos.angle(CENTER, ServoJewel.SPEED_FAST, self.right_hip, self.left_hip)

# -- Cuties -----------------------------------------------------------------------------------------------------------

    def say_hello_left(self):
        self.lean_to_left(ServoJewel.SPEED_SLOW)

        for i in range(0, 3):
            self.servos.angle(MAX, ServoJewel.SPEED_SLOW, self.right_ankle)
            utime.sleep_ms(50)
            self.servos.angle(MIN, ServoJewel.SPEED_SLOW, self.right_ankle)
            utime.sleep_ms(50)

        self.undo_lean_to_left(ServoJewel.SPEED_SLOW)

    def say_hello_right(self):
        self.lean_to_right(ServoJewel.SPEED_SLOW)

        for i in range(0, 3):
            self.servos.angle(MAX, ServoJewel.SPEED_SLOW, self.left_ankle)
            utime.sleep_ms(50)
            self.servos.angle(MIN, ServoJewel.SPEED_SLOW, self.left_ankle)
            utime.sleep_ms(50)

        self.undo_lean_to_right(ServoJewel.SPEED_SLOW)

    def shake_left(self):
        self.lean_to_left(ServoJewel.SPEED_SLOW)

        for i in range(0, 3):
            self.servos.angle(MAX, ServoJewel.SPEED_FAST, self.right_hip)
            utime.sleep_ms(50)
            self.servos.angle(MIN, ServoJewel.SPEED_FAST, self.right_hip)
            utime.sleep_ms(50)

        self.servos.angle(CENTER, ServoJewel.SPEED_FAST, self.right_hip)
        self.undo_lean_to_left(ServoJewel.SPEED_SLOW)

    def shake_right(self):
        self.lean_to_right(ServoJewel.SPEED_SLOW)

        for i in range(0, 3):
            self.servos.angle(MAX, ServoJewel.SPEED_FAST, self.left_hip)
            utime.sleep_ms(50)
            self.servos.angle(MIN, ServoJewel.SPEED_FAST, self.left_hip)
            utime.sleep_ms(50)

        self.servos.angle(CENTER, ServoJewel.SPEED_FAST, self.left_hip)
        self.undo_lean_to_right(ServoJewel.SPEED_SLOW)


# -- Jumping ----------------------------------------------------------------------------------------------------------

    def jump(self, delay_between_setting=200):
        self.servos.angle(30, self.right_ankle)
        self.servos.angle(150, self.left_ankle)
        utime.sleep_ms(delay_between_setting)
        self.servos.angle(90, self.right_ankle, self.left_ankle)

# -- Walking ----------------------------------------------------------------------------------------------------------

    def walk_forward(self, speed=ServoJewel.SPEED_MEDIUM):
        self.lean_to_right(speed)
        self.twist_right(speed)
        self.undo_lean_to_right(speed)

        self.lean_to_left(speed)
        self.twist_left(speed)
        self.undo_lean_to_left(speed)

    def walk_backward(self, speed=ServoJewel.SPEED_MEDIUM):
        self.lean_to_right(speed)
        self.twist_left(speed)
        self.undo_lean_to_right(speed)

        self.lean_to_left(speed)
        self.twist_right(speed)
        self.undo_lean_to_left(speed)

# -- Stepping ----------------------------------------------------------------------------------------------------------

    def step_backward(self, speed=ServoJewel.SPEED_MEDIUM):
        self.lean_to_right(speed)
        self.twist_left(speed)
        self.undo_lean_to_right(speed)

        self.lean_to_left(speed)
        self.twist_center(speed)
        self.undo_lean_to_left(speed)

    def step_forward(self, speed=ServoJewel.SPEED_MEDIUM):
        self.lean_to_right(speed)
        self.twist_right(speed)
        self.undo_lean_to_right(speed)

        self.lean_to_left(speed)
        self.twist_center(speed)
        self.undo_lean_to_left(speed)

# -- Turning ----------------------------------------------------------------------------------------------------------

    def turn_right(self, speed=ServoJewel.SPEED_MEDIUM):
        self.lean_to_right(speed)
        self.servos.angle(MIN, speed, self.right_hip)
        self.undo_lean_to_right(speed)

        self.lean_to_left(speed)
        self.servos.angle(CENTER, speed, self.right_hip)
        self.undo_lean_to_left(speed)

    def turn_left(self, speed=ServoJewel.SPEED_MEDIUM):
        self.lean_to_left(speed)
        self.servos.angle(MAX, speed, self.left_hip)
        self.undo_lean_to_left(speed)

        self.lean_to_right(speed)
        self.servos.angle(CENTER, speed, self.left_hip)
        self.undo_lean_to_right(speed)


RIGHT_EYE = 0
LEFT_EYE = 1

_eyes = None
_legs = None


def legs():
    global _legs

    if not _legs:
        _legs = Legs()

    return _legs

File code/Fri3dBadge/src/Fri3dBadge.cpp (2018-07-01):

#include "Fri3dBadge.h"

#include "config.h"

// IO controle pinnen voor de vier servo's, in volgorde van SERVO1,...
int pinnen[4] = { SERVO1_PIN, SERVO2_PIN, SERVO3_PIN, SERVO4_PIN };

Fri3dBadge::Fri3dBadge() 
{
	// creëer servo objecten voor de 4 servos
	// for(int i=0; i<4; i++) {
		// this->servos[i] = new Servo(pinnen[i]);
	// }
}

// Servo Fri3dBadge::servo(int index) {
	// return *(this->servos[index]);
// }

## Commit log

2017-11-26 prepared repository for next badge
    [fri3d_badge_2016.brd, fri3d_badge_2016.csv, fri3d_badge_2016.sch]
2017-12-17 added datasheet for ESP32
2017-12-21 added datasheets for prototype 1 components
2017-12-21 added schematic and board layout for prototype 1
    [fri3d-badge-2018.brd, fri3d-badge-2018.sch]
2017-12-21 fixed some silkscreen issues (tValues -> tNames)
    [fri3d-badge-2018.brd]
2017-12-21 added functional sections to schematic
    [fri3d-badge-2018.sch]
2017-12-21 added images of proto-1 board layout/EC rendering
2017-12-21 added missing section title
    [fri3d-badge-2018.sch]
2017-12-21 improved position of schematic components a bit
    [fri3d-badge-2018.sch]
2017-12-21 improved position of net names a bit
    [fri3d-badge-2018.sch]
2017-12-30 unified values
    [fri3d-badge-2018.brd, fri3d-badge-2018.sch]
2018-01-11 moved prototype 1 PCB to v1 folder/project
    [fri3d-badge-2018.brd, fri3d-badge-2018.sch]
2018-01-11 start proto 2 with new dimension and usb connector
    [fri3d-badge-2018.brd, fri3d-badge-2018.sch]
2018-01-20 completed draft of schematic for prototype 2
    [fri3d-badge-2018.brd, fri3d-badge-2018.sch]
2018-01-21 added extension headers + expansion board
    [fri3d-badge-2018.brd, fri3d-badge-2018.sch]
2018-01-31 completed first layout prototype 2
    [fri3d-badge-2018.brd, fri3d-badge-2018.sch]
2018-02-04 changed step-up inductor + testpoints/shortcuts
    [fri3d-badge-2018.brd, fri3d-badge-2018.sch]
2018-02-04 changed pin config for first prototype PCB
2018-02-11 fixed USB GND/SHIELD issue
    [fri3d-badge-2018.brd, fri3d-badge-2018.sch]
2018-02-11 added ESD protection, enlarged power planes/traces
    [fri3d-badge-2018.brd, fri3d-badge-2018.sch]
2018-02-12 added polygons for GND near DW-01 + cut corners
    [fri3d-badge-2018.brd]
2018-02-13 redid USB entry/ESD + cleaned up silk
    [fri3d-badge-2018.brd]
2018-02-15 further improved USB/ESD/FT traces
    [fri3d-badge-2018.brd, fri3d-badge-2018.sch]
2018-02-19 redid USB intake again, uncrossing lines at conn
    [fri3d-badge-2018.brd, fri3d-badge-2018.sch]
2018-02-19 swapped position of buttons R and A
    [fri3d-badge-2018.brd]
2018-02-22 fixed incorrect footprint for sx1308
    [fri3d-badge-2018.brd, fri3d-badge-2018.sch]
2018-02-22 removed old usb connector
2018-02-22 added "datasheets" for other LEDs
2018-02-22 added CAM file for PCBWay
2018-02-22 added separate expansion PCB
    [expansion.brd, expansion.sch]
2018-02-26 legacy version of PCBWay CAM file
2018-03-16 added 3 missing traces/connections to ESP
    [fri3d-badge-2018.brd, fri3d-badge-2018.sch]
2018-03-25 several bugfixes in schema and layout
    [fri3d-badge-2018.brd, fri3d-badge-2018.sch]
2018-03-26 "fixed" incorrect labels ;-)
    [fri3d-badge-2018.brd, fri3d-badge-2018.sch]
2018-03-26 added buttons support
2018-03-30 added final prototype 2 schema & layout PDF
2018-04-12 modified the repository structure
    Made use of branches to identify the version of the badge
    [expansion.brd, expansion.sch, fri3d-badge-2018.brd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]
2018-04-16 Added support for micropython
    [expansion.brd, expansion.sch, fri3d-badge-2018.brd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]
2018-04-17 Added the servo library
2018-04-17 AcceleroMeter support
    Added a port of the raspi-smbus library to micropython. Unable to test yet, since I do not have the accelerometer at hand
2018-05-01 Fun with shift registers
    It seems the micropython code is running too slow. The shift.py contains the code I am running on an ESP32 with shift registers and a led matrix attached. For some reason the leds keep on blinking
2018-05-13 v3 design files added
    First prototype redesigned in Altium Designer 18.1 and with a complete
    new mechanical design.
    [Bill of Materials-Fri3D_2018_00.xls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]
2018-05-13 added datasheets for prototype 3 components
    Updated datasheet list
2018-05-22 Repo cleanup, added new badge design
    [Bill of Materials-Fri3D_2018_00.xls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]
2018-05-23 first docs on using the ESP32 in the Arduino IDE
2018-06-13 Added Arduino + VS Code + PlatformIO documentation and example.
2018-06-21 Air Jewel Rev.00 added
    [Bill of Materials-Fri3D_Air_2018_00(Not Mounted).xls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]
2018-06-21 Air Jewel Rev.01 added
    Design files for the newer version of the Air jewel have been added
    [Bill of Materials-Fri3D_Air_2018_01(Not Mounted).xls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]
2018-06-21 Bot Jewel Rev.00 added
    This Jewel is part of the Fri3d Bot kit
    [Bill of Materials-Fri3D_Bot_2018_00(Not Mounted).xls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]
2018-06-22 Badge v4 added
    Updated version of the badge, includes pull-ups on user buttons, expansion connectors have been replaced with SMD connectors, routing has been updated.
    [Bill of Materials-Fri3D_2018_01(Not Mounted).xls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]
2018-07-01 code housekeeping. Moved some things around to make it easier to program with a lesser footprint.
2018-07-12 added the firmware we are using today as well as a flash script
    [partitions_mpy.csv]
2018-07-17 arduino code moved to its own repository

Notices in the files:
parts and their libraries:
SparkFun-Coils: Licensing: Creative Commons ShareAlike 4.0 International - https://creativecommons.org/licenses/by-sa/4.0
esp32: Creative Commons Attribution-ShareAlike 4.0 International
